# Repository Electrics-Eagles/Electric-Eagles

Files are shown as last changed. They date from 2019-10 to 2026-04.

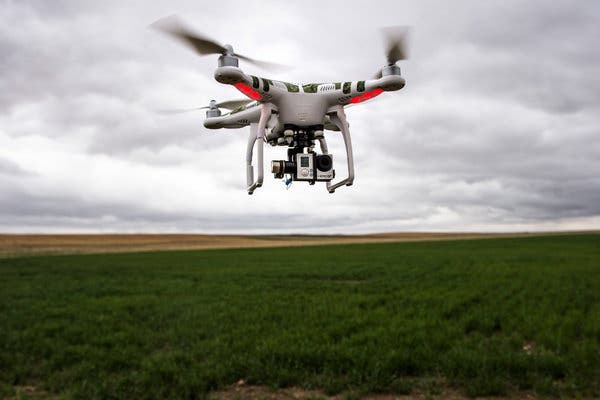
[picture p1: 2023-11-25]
Studio/Electrics Eagles Setup Studio/src/main/resources/Wirzard.FXML/template/dji.jpg

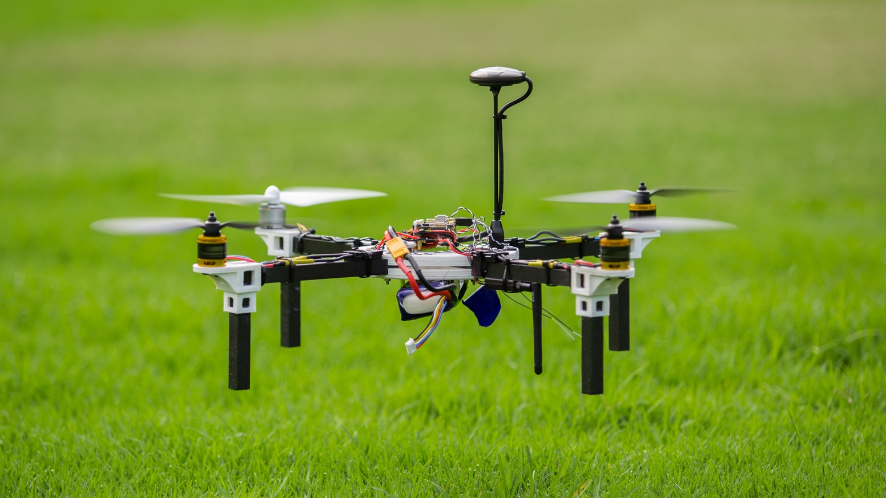
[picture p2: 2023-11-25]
Studio/Electrics Eagles Setup Studio/src/main/resources/drone_imange.jpg

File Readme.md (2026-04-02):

# Electric Eagle Drone Project
Project Overview  
The Electric Eagle Drone Project is a collaborative effort led by a team of three dedicated individuals:  
* Alex Zaslvskis
* Mike Zaslvskis
* Daniel Zile

# Objectives
Our primary objective was to create a simple and flexible platform for developing Arduino-based drones. The project is an ongoing endeavor, and you can find detailed information on our official website.

# Technologies and Tools Used
During the creation of this project, we utilized various technologies and tools to ensure its success:

1. YMFC-AL Version 1.4: Our flight control software.
2. Arduino IDE 1.8.10 and 1.0.6: The integrated development environment for programming the Arduino boards.
3. Sublime Text 3.22: A text editor for code development.
4. Python 3.7.6: Used for scripting and automation.
5. Java 11u06: Required for certain components.
6. Deviot: An Arduino IDE package manager.
7. Arduino Nano v3 (CH340): The microcontroller used in our project.
8. Motors and ESC from DJI Phantom 1 (FC40): High-quality propulsion components.
9. DJI 450 Frame: The drone's frame for stability and durability.
10. 2200mAh 11.1V Battery: Power source for the drone.
11. SMD Capacitors (1206): Components for electrical stability (2μF, 1μF, 0.1nF).
12. SMD Resistors (1206): Components for electronic control.
13. And your three brilliant minds: Our team's expertise and creativity.
# Acknowledgments
We extend our sincere gratitude to our physics teacher,George Dalidovich, for providing invaluable guidance and support throughout this project.
# What next
For further details and updates, contact us on GitHub or email:  electricseagles2020@gmail.com

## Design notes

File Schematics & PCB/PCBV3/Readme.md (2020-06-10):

These PCB board was update signal to PPM mode for transmit. Instead of four pmw mode pin. 
Additionally, we added GPS module for our drone. It will second board.

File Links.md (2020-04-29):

Add Here any links that we use for making drone.
-------------------------------------------------------PID--------------------------------------------------------
 https://oscarliang.com/quadcopter-pid-explained-tuning/
https://www.crossco.com/blog/basics-tuning-pid-loops/
https://profpv.ru/chto-takoe-pid-na-chto-vliyaet-i-kak-nastroit/
https://www.youtube.com/watch?v=tgQDJ73w7Uc
https://habr.com/ru/company/technoworks/blog/216437/
https://github.com/it-workshop/Quadrocopter/wiki/Software
https://habr.com/en/post/145991/
https://habr.com/en/post/143388/
https://multicopterwiki.ru/index.php/Теория_настройки_ПИД_/_PID
https://clever.coex.tech/ru/pid_tuning.htmlw
https://sites.google.com/site/webstm32/pid_reg
https://habr.com/ru/post/227425/
http://jsfiddle.net/limon_spb/ZPmPh/
https://dspace.ucuenca.edu.ec/bitstream/123456789/21401/1/IEE_17_Romero%20et%20al.pdf
http://isd-soft.com/tech_blog/tuning-pid-regulator/

--------------------------------------------------------PID---------------------------------------------------------

--------------------------------------------------------Drone_making------------------------------------------------
http://www.electronoobs.com/eng_robotica_tut6_1.php
http://andrew.gibiansky.com/downloads/pdf/Quadcopter%20Dynamics,%20Simulation,%20and%20Control.pdf
https://www.slideshare.net/mobile/corradosantoro/quadcopter-31045379
https://www.google.co.uk/amp/s/www.wired.com/2017/05/the-physics-of-drones/amp
https://diymodeling.appstate.edu/sites/diymodeling.appstate.edu/files/drone.pdf
https://www.quora.com/What-are-the-mathematics-of-drone-quadcopter-flight-stabilization
http://archives.math.utk.edu/ICTCM/VOL27/A029/paper.pdf
https://howtomechatronics.com/tutorials/arduino/arduino-brushless-motor-control-tutorial-esc-bldc/
https://howtomechatronics.com/tutorials/arduino/arduino-brushless-motor-control-tutorial-esc-bldc/
https://www.youtube.com/watch?v=kyX9cRxJNdo
https://www.youtube.com/watch?v=DYpHB-LfloI&t=4s
http://www.brokking.net/ymfc-al_main.html
--------------------------------------------------------Drone_making------------------------------------------------
--------------------------------------------------------Usage of Drones---------------------------------------------
https://www.dummies.com/consumer-electronics/drones/popular-uses-for-drones/
--------------------------------------------------------Drone phyics------------------------------------------------
https://www.quora.com/Why-cant-all-the-motors-of-a-quadcopter-rotate-in-the-same-direction
--------------------------------------------------------------------------------------------------------------------

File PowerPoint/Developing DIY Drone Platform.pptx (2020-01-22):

## Developing DIY Drone Platform. Working with GitHub.

## FFirst of All we should to finish a team group.

- 1) Dayo
- 2) Flami
- 3) Jaan
- 4) TJ ?

## Second Task is a understand our project name.

- My Idea is Electrics Eagles Open Source Arduino based Drone Development platform . Shortly EEOSABDDP.

## Also We need to made short and remembered name for (DDP)*

- *Drone development Platform.

## After I we should to plan our project.

- Read Rules
- Start Answer Questions. (Maybee Jaan)

## We need to think about our Software / Hardware Products names.

## Ask yourself are you ready to hard work?

## We should decide so what who do.

- Hardware Planning Everybody.
- Making Library from our code Mike
- Write Normal Sublime Text 3 & VS Code Plugins Danio
- PC Software ( Setup Wizard , first check status designer … ) Alex
- Writing report ( Somebody else ( Jaan)).
- Make tutorials (Everybody)

## What we had now.

- 1) Bad working Sublime Text 3 Plugin
- 2) Drone Core Firmware
- 3) Flying hardware.
- 4) Some references.
- We should:
- Make Hardware easyer
- Rewrite Sublime Text Plugin
- Write PC Tool
- Write Report
- Make tutorials.
- Pack Core Firmware as Library

## Programming Lanuages

- Sublime Text 3 & Vs Code Plugin (Python + CSS+ Pyside2)
- PC Tool is a Java
- Drone Core is a C++ / C / asm

## Working with GitHub.

## How Work With GitHub.

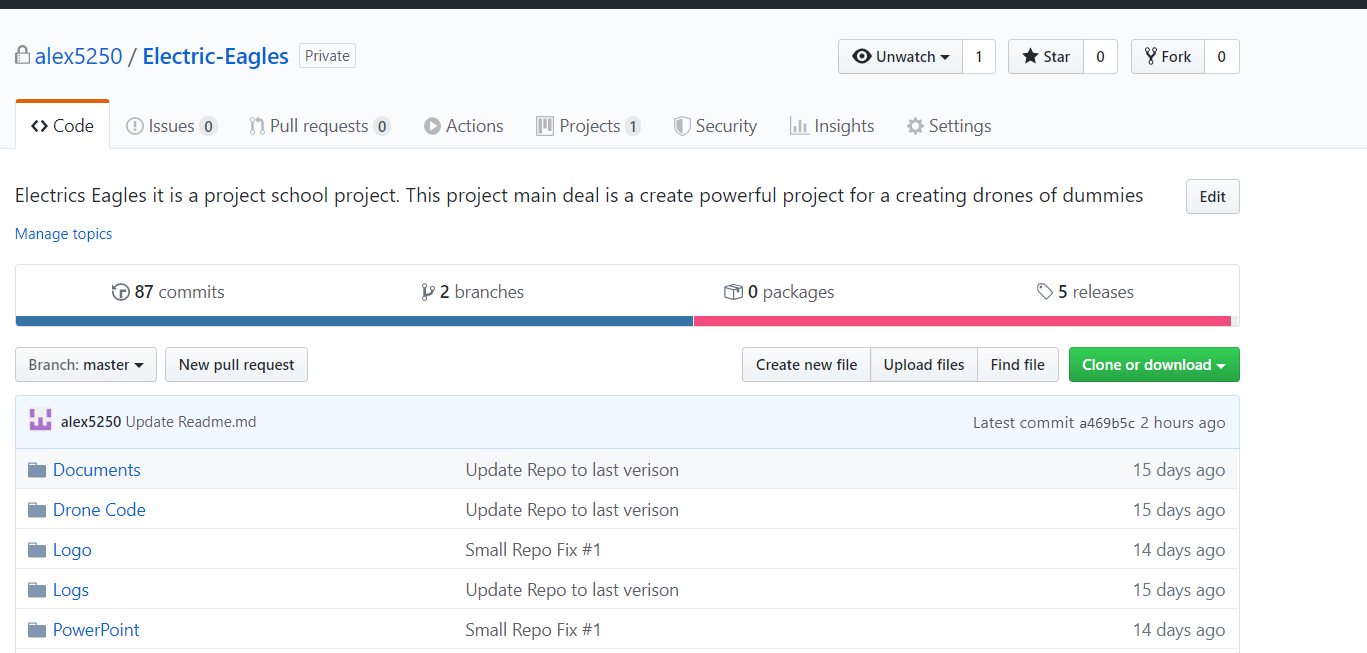
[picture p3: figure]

## Anyway our GitHub is a large difficult system. It has a chart witch helps found what you need.

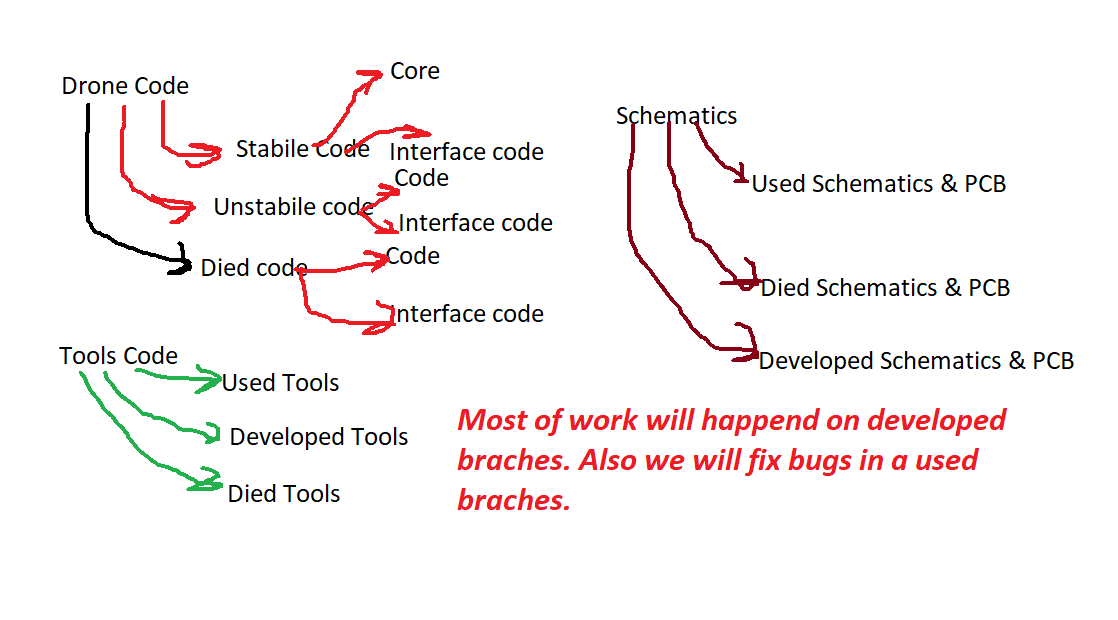
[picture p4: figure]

## Working with GitHub.

- First of all you should register on it. After it send your nickname to me I will add you to our repo.
- Main Idea of it that everybody can edit code, add resources ,fix bugs, add tasks. So I don`t do everything.

## We had a some interesting parts of GitHub Repo. It is a project.

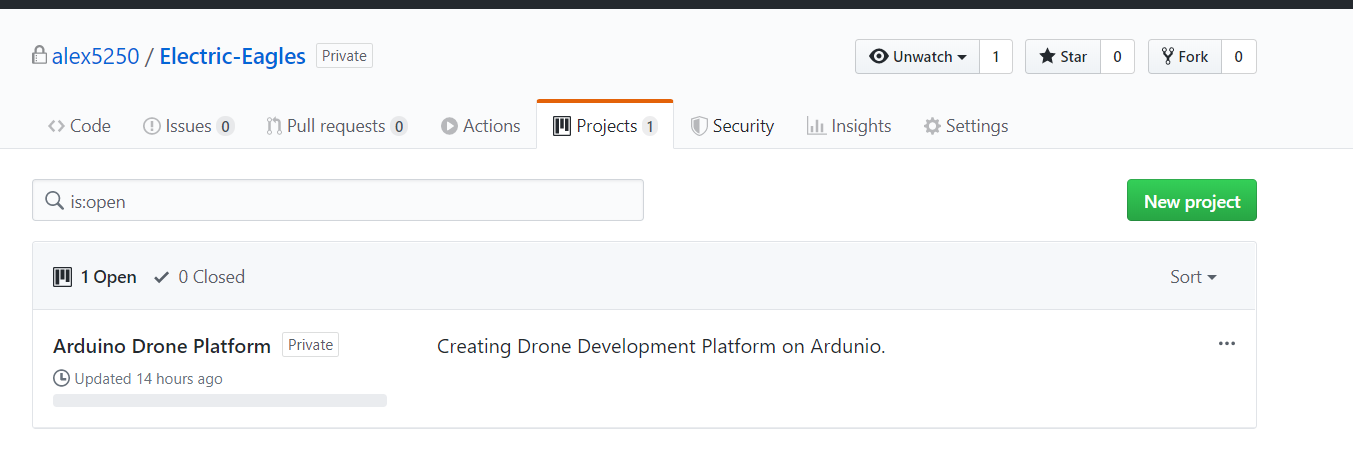
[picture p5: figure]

## Here is written all tasks that we do. You can take it move it to progress and write your name. If you done task move it to done.

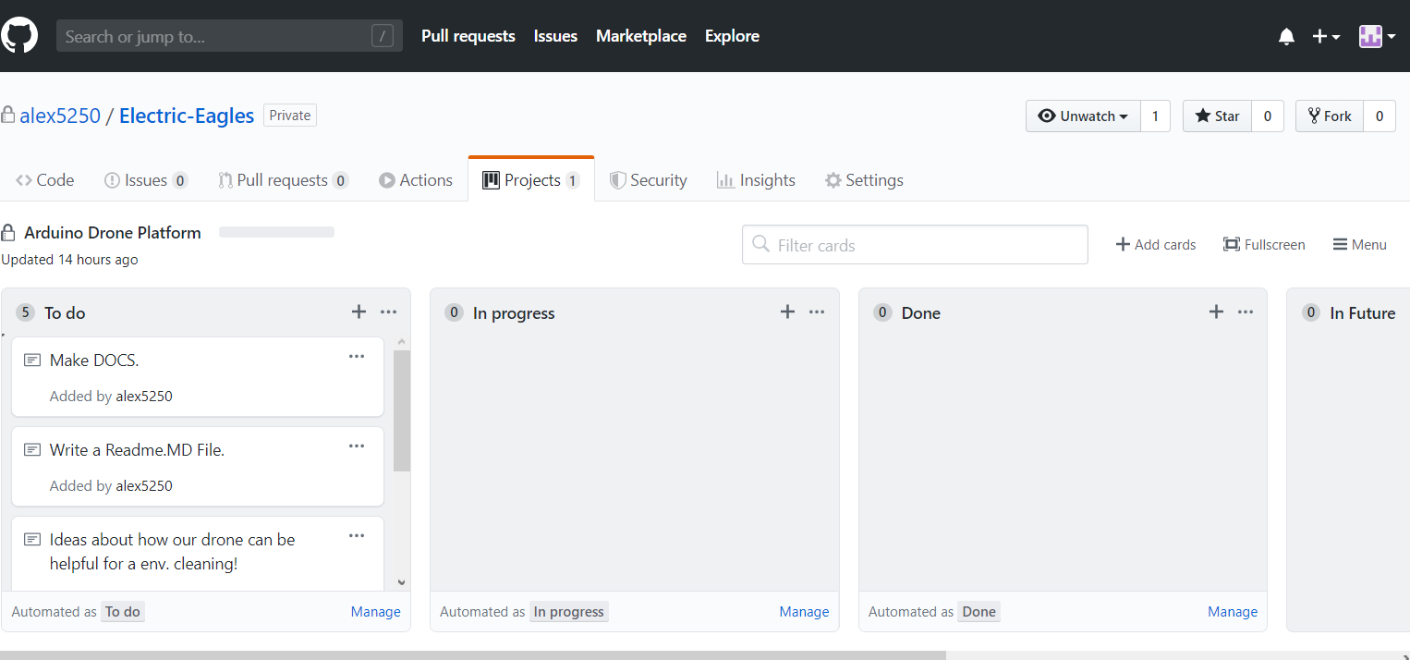
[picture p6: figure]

Alex

Alex

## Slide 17

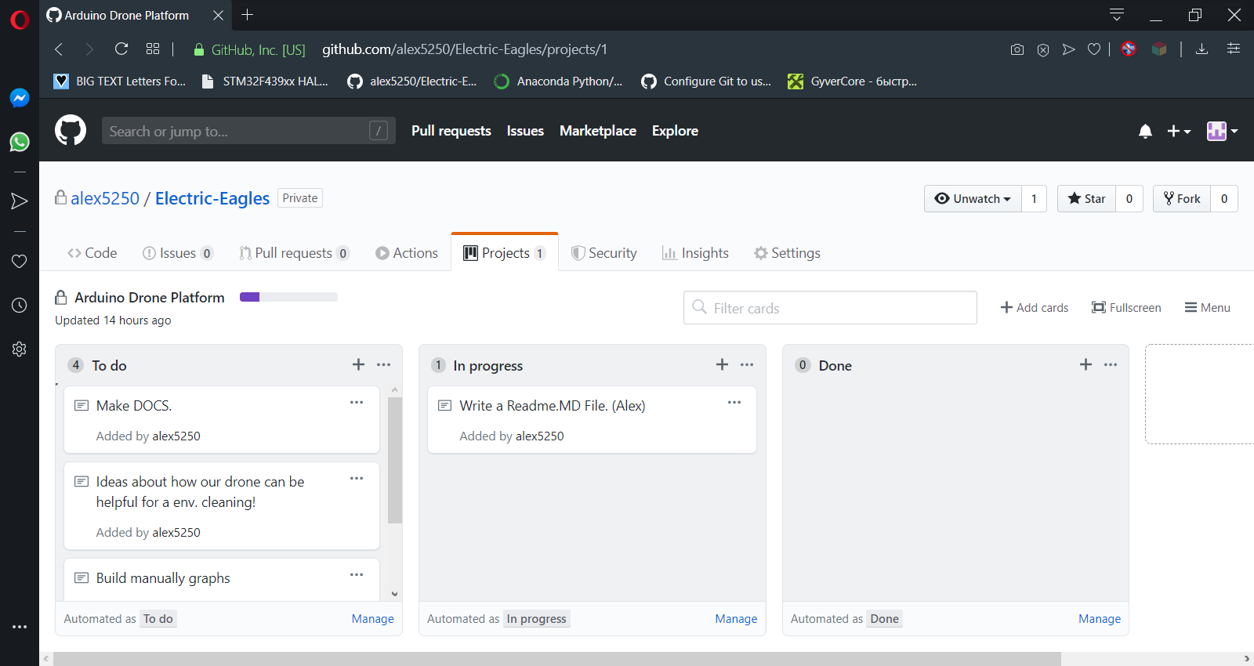
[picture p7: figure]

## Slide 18

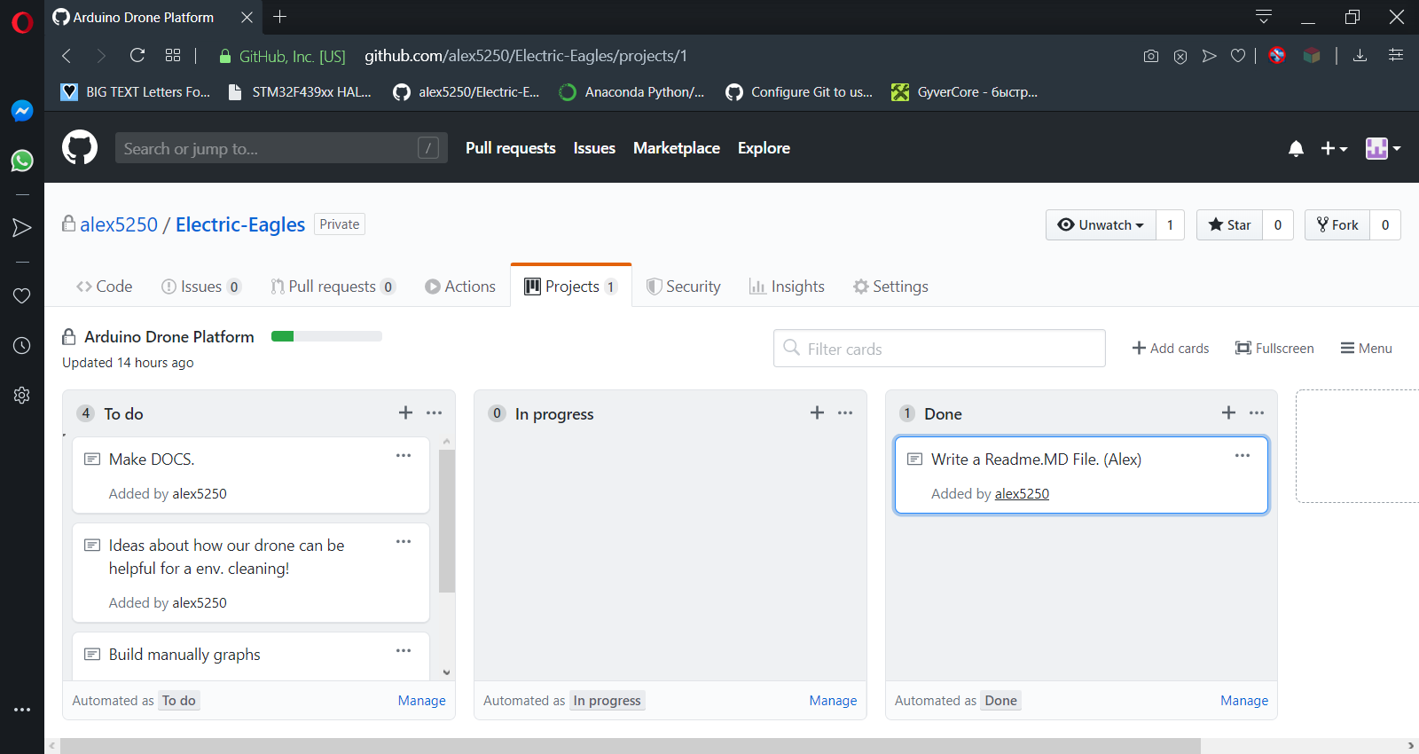
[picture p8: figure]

## If you found a bug in code & hardware. Make report in Issue page. Explain it mostly understandable that you can.

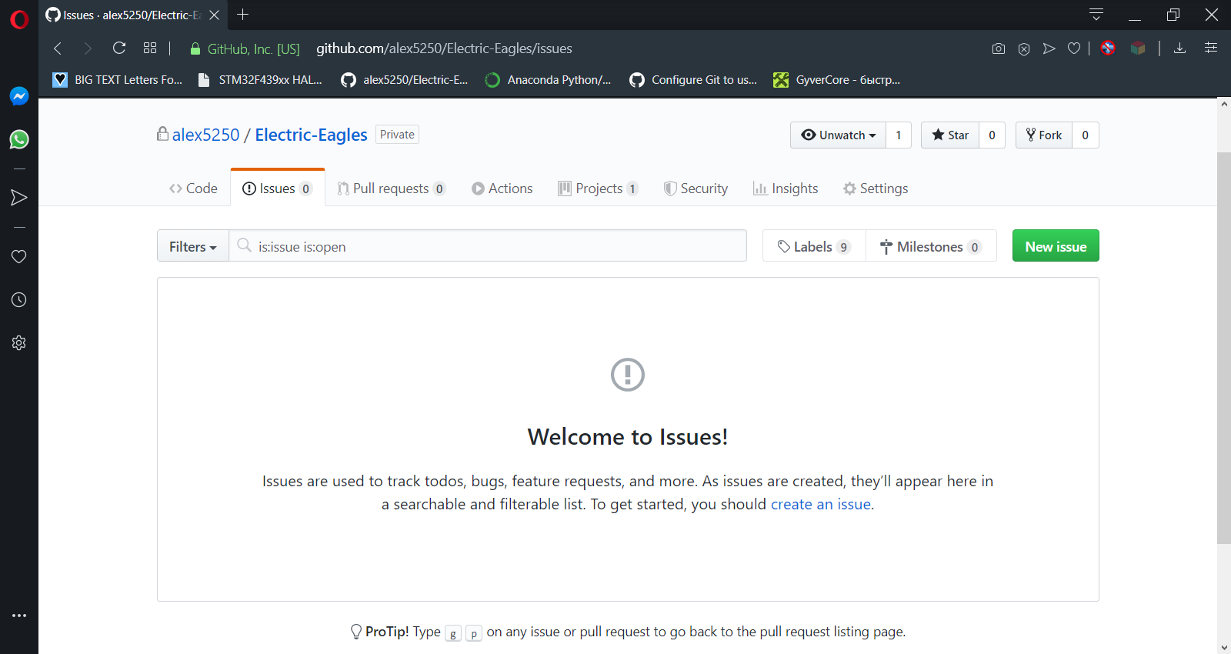
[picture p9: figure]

## All links goes here.

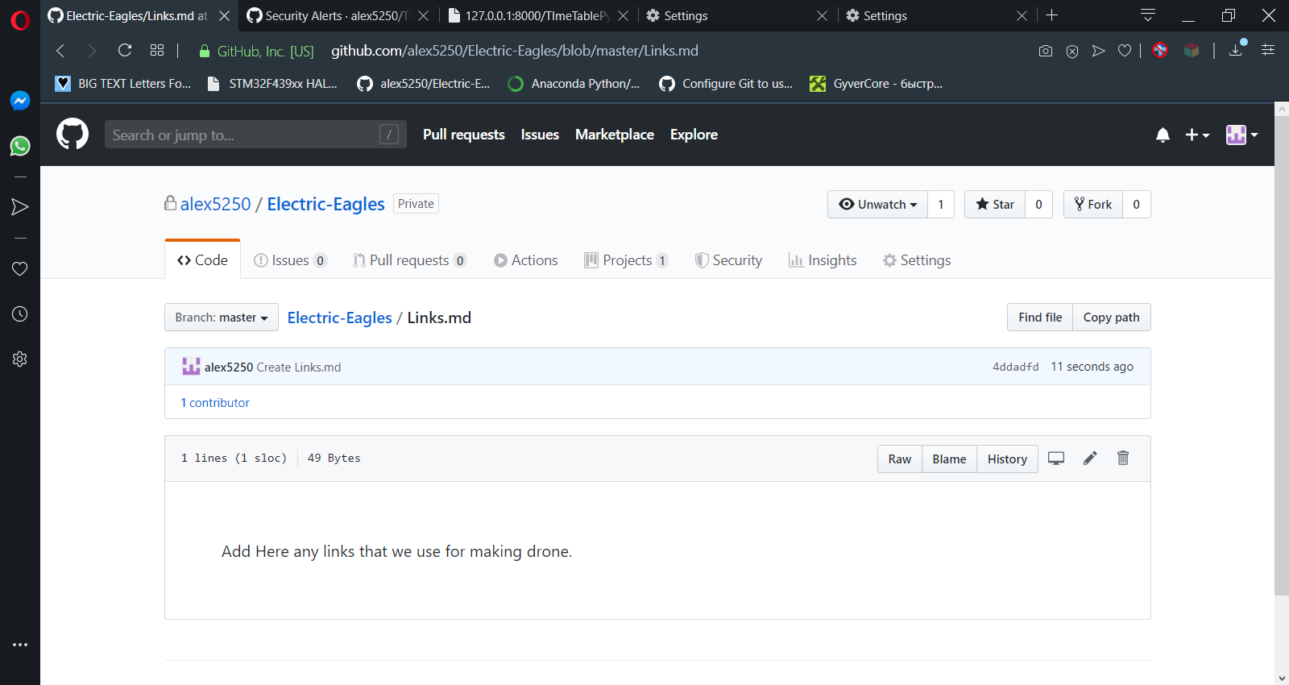
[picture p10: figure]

## Any actual software you can found it releases branch.

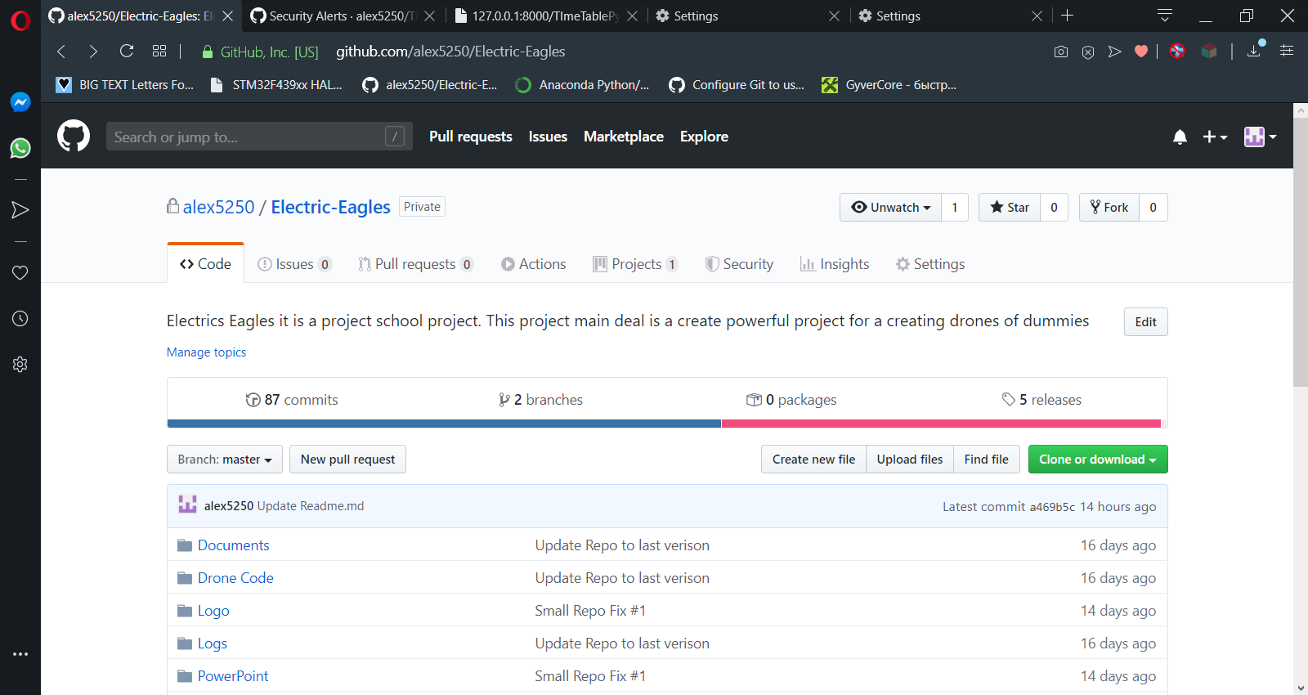
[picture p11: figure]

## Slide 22

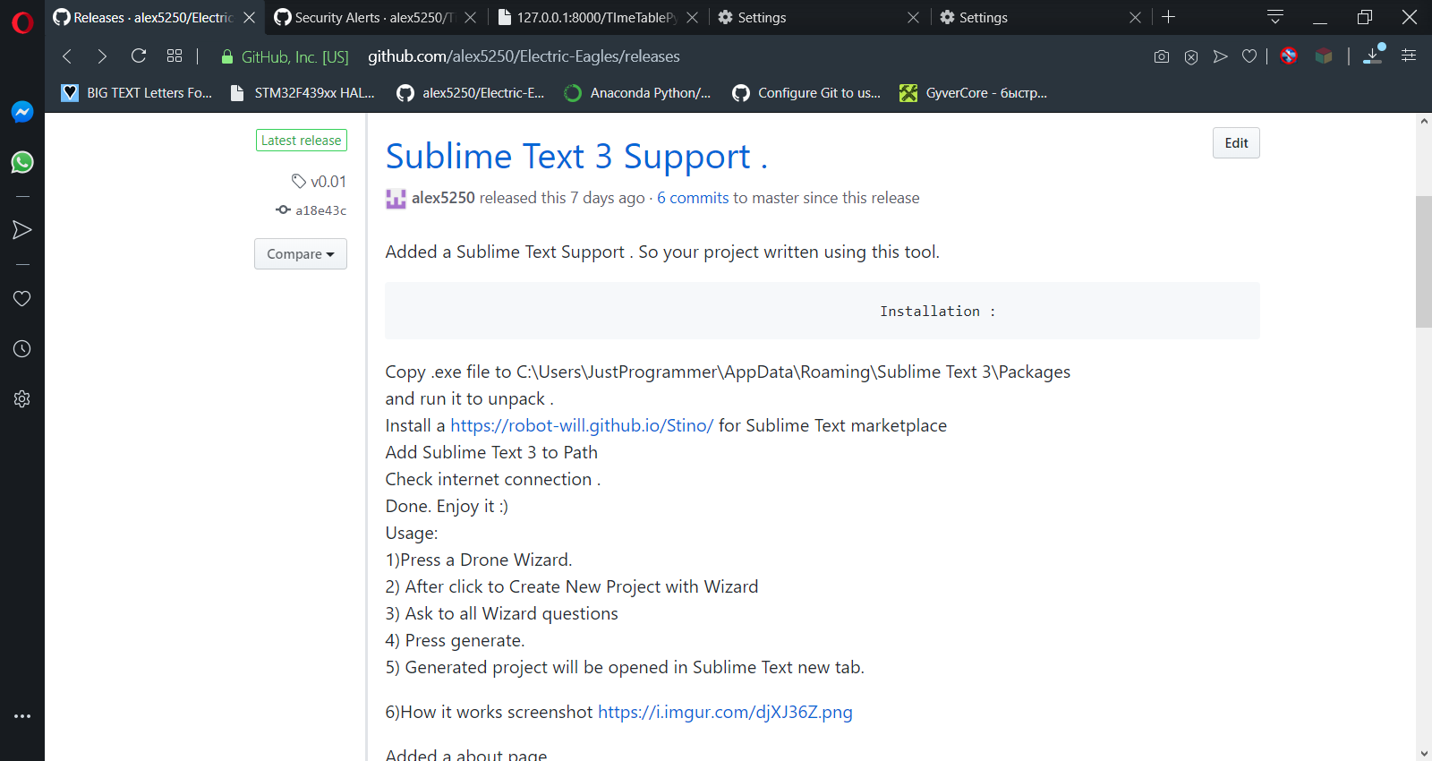
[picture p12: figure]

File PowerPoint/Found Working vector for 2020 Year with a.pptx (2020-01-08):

## Found Working vector for 2020 Year with a drones

## Also Working With Gyro Data Maybe we had a problem with vibration isolation.

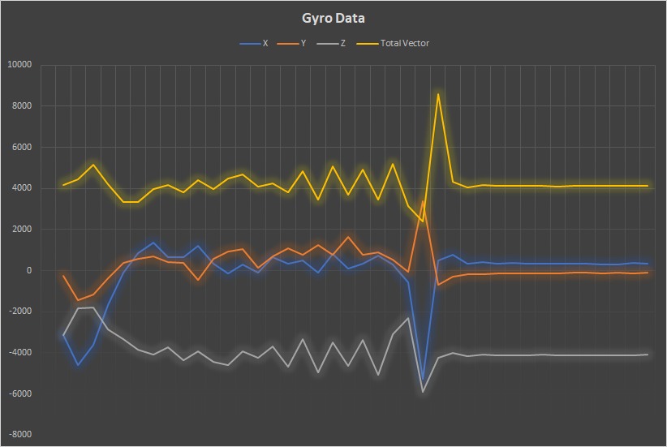
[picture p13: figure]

## Also We can try too work with subtrims

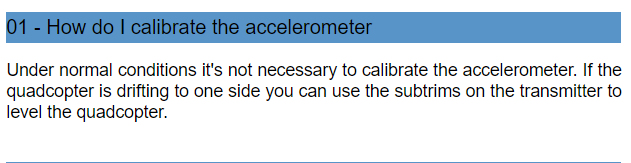
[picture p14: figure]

## Also We can do this one and make SOLUTION

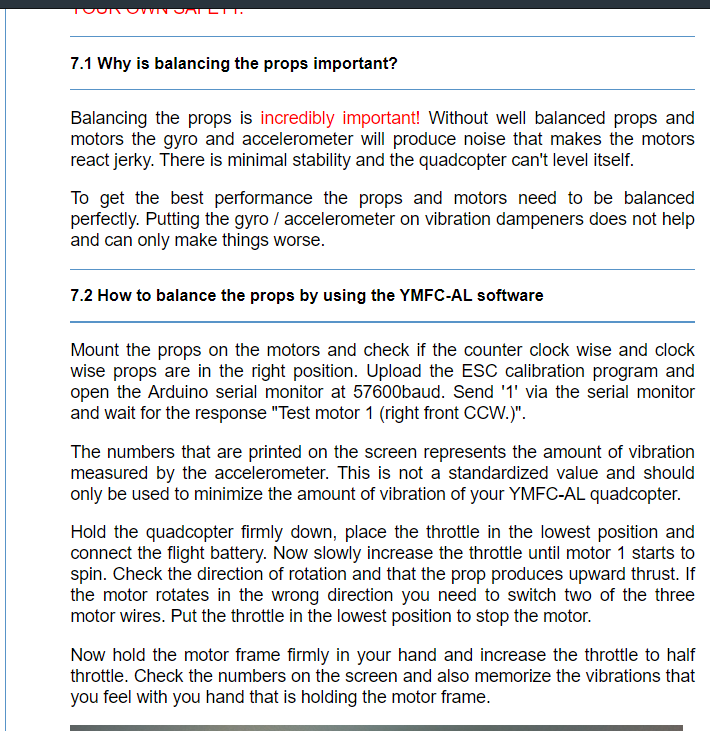
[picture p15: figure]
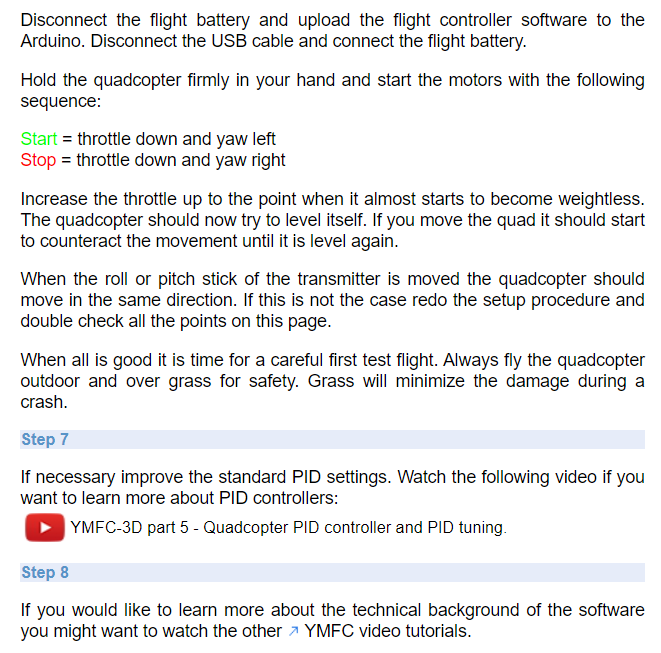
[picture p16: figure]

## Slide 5

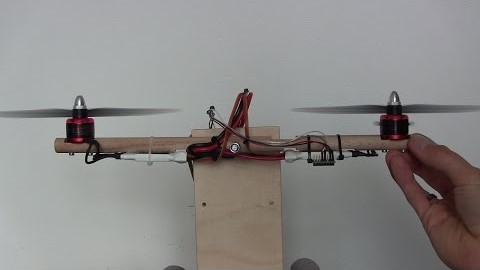
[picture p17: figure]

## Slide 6

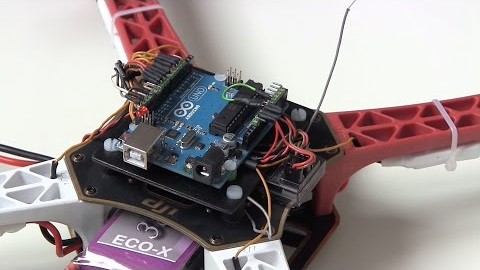
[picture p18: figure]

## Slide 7

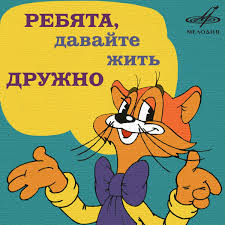
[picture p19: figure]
Картинки по запросу ребята давайте жить дружно
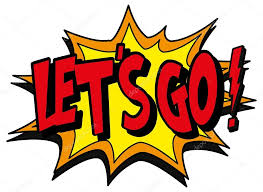
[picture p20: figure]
Картинки по запросу дуеёы пщ

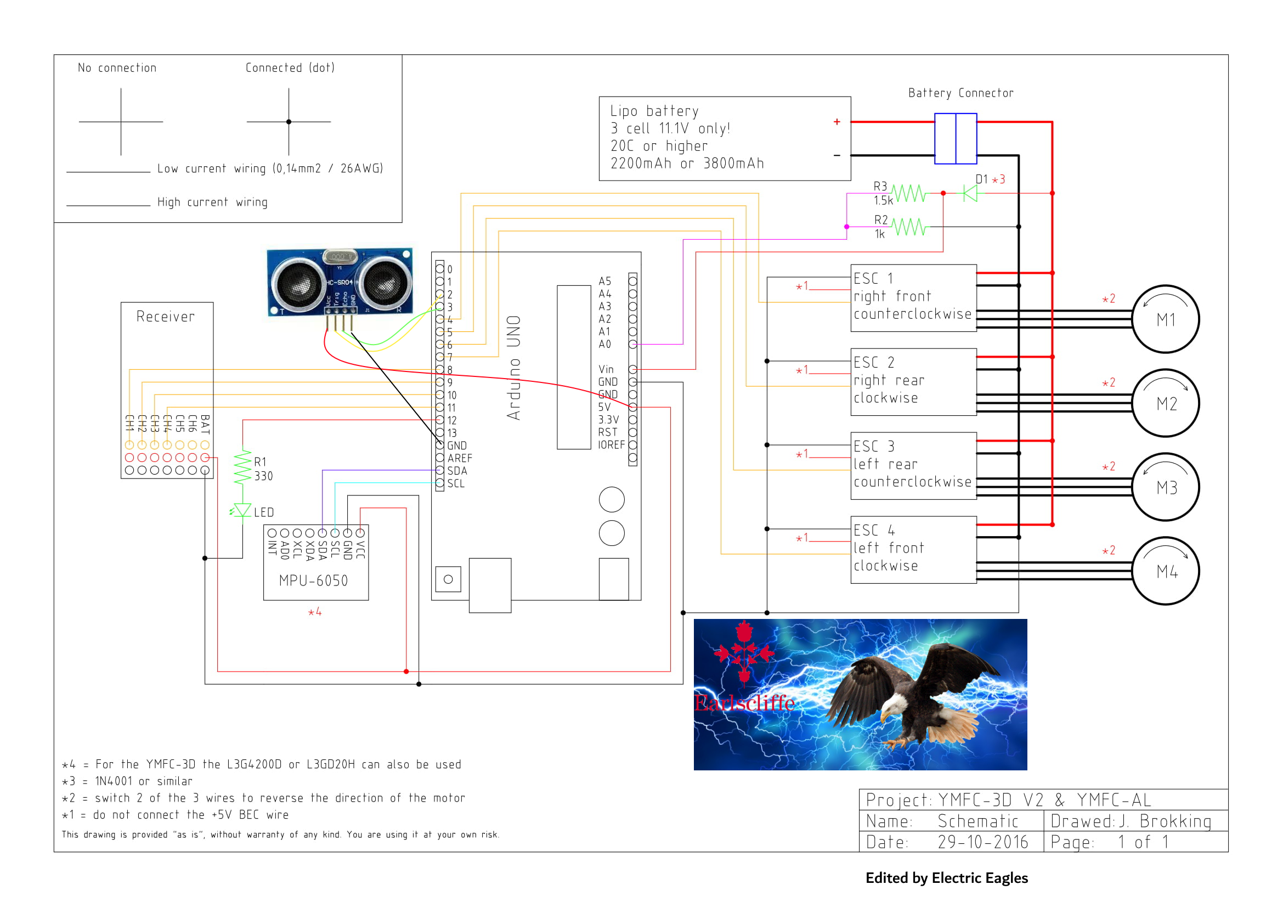
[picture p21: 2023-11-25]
Schematics & PCB/Drone PCB/EarclifeDrone_schematic.png

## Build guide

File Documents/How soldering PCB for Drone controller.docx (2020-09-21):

How soldering PCB for Drone controller

You may need before do:

List necessary components

Name of components | Qty. (pcs) | Number components in PCB | Remark | Link to ordering components
Diode M7 | 1 | D1
Resistor 1.5 kohm with size SMD1206 | 1 | R1 | Size SMD with code 1206
Resistor 1 kohm with size SMD1206 | 1 | R2 | Size SMD with code 1206
Ceramic capacitor with size SMD1206 | 1 | C1 | Size SMD with code 1206
Electric capacitor 470 µF | 1 | C2 | Or any capacitor with recommend more than 220 µF. And minimal voltage requirement more 16 V.
L7805 voltage regulator | 1 | 7805
MPU6050 gyroscope board | 1 | U2
Arduino nano | 1 | ARD1
Buzzer with generator, which it compuse less than 40 mA and normal voltage 5 V | 1 | U3
PCB with provided circuit | 1
2.54mm 3-pin header male with angle 90° | 4 | With short text about ESC | For connect each ESC to flight controller
Wire with female header 2.54 mm | 6 (with mixed color of wires) | U1 | For receiver Fly-sky

1. Solder SMD-components, which resistor and capacitor with following normal value and number of places of this PCB.
2. Solder electric capacitor and buzzer, but it is very important follow polarity where marked symbol “+” – plus polarity. Otherwise polarity, may be damage these components.
3. Solder L7805 voltage regular. Follow correct pin of L7805 into board. Follow picture.
4. Solder wires for receiver Fly-sky. If you have two header female in each wire, cut one this header of wire. Clear bit part isolation of each wire. Solder wire into board with following number of components.
5. Gyroscope and Arduino nano controller provided header male with apporation number of pins.
  5.1 First solder header into these boards.
  5.2 Pick these modules into PCB, but you need make sure correct pin before soldering. Follow this picture below. Be carefully! Otherwise, board may death if incorrect pick module into board. You may need to check correctly pin via multimeter. Simple test polarity between modules and PCB.
  5.3 Recheck your soldered board, before connect power, include pins for receiver and ESC. Sometimes don’t marked polarity in PCB. You can find polarity via multimeter where it is plus and minus, pin, signal. Follow picture below.

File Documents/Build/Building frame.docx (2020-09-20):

Building frame

1) Step one take the lowest holder and turn it back
2) Install red motor holder
  a. Be careful the red motor holder should be on dig anal of red one .

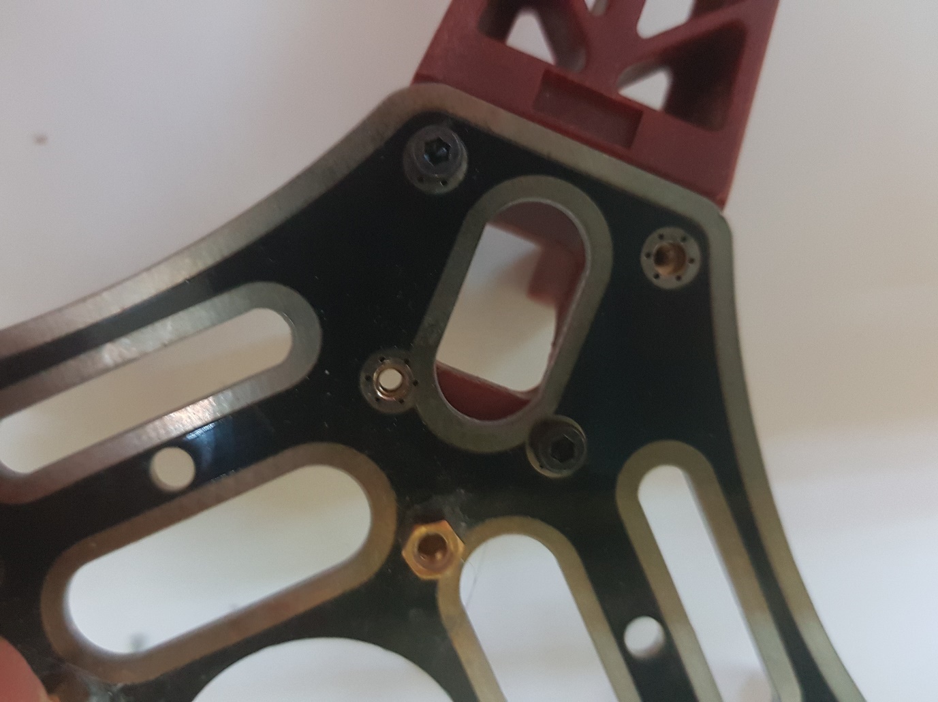
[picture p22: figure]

Warring . Install 4 screws and make sure that they installed correctly

Continue this for 3 left motor holders .

As result you should get :

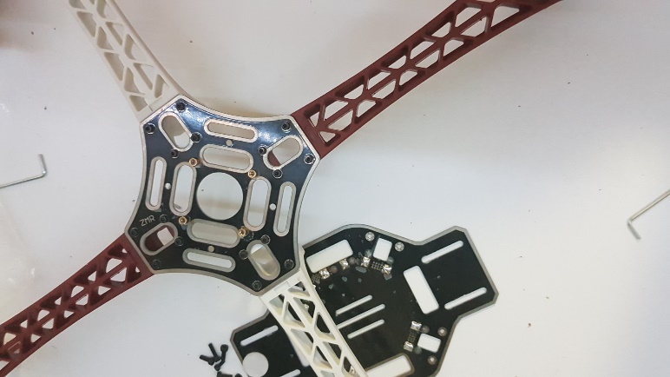
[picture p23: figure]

Turn back the drone:

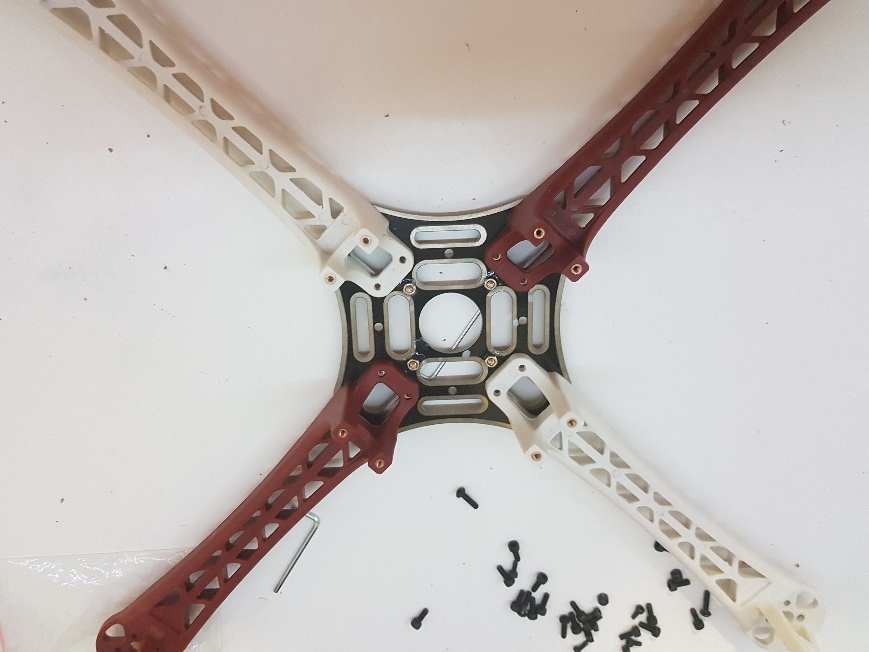
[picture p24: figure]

Turn over down plate and install it by 2 screws:

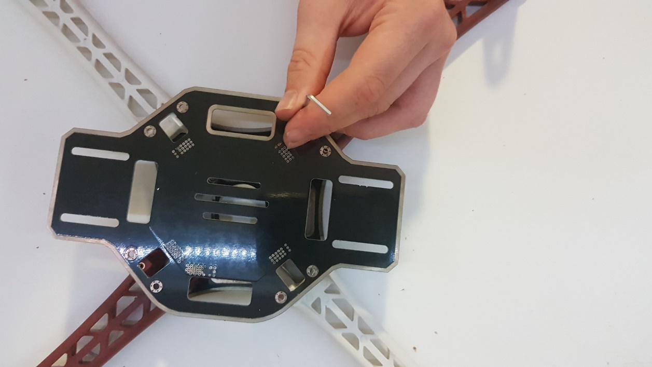
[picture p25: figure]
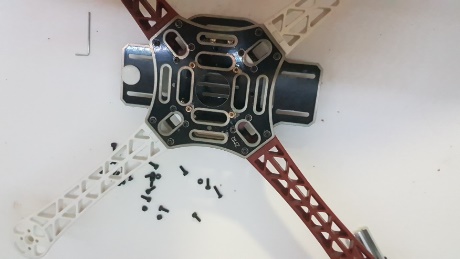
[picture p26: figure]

Turn it back and result you should get:

Is motor install time

Check motors

Warring has different rotation so same colour screw motors should be installed diagonally

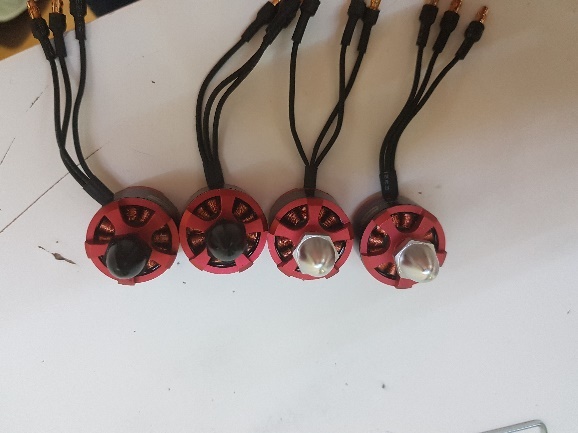
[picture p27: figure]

Like that:

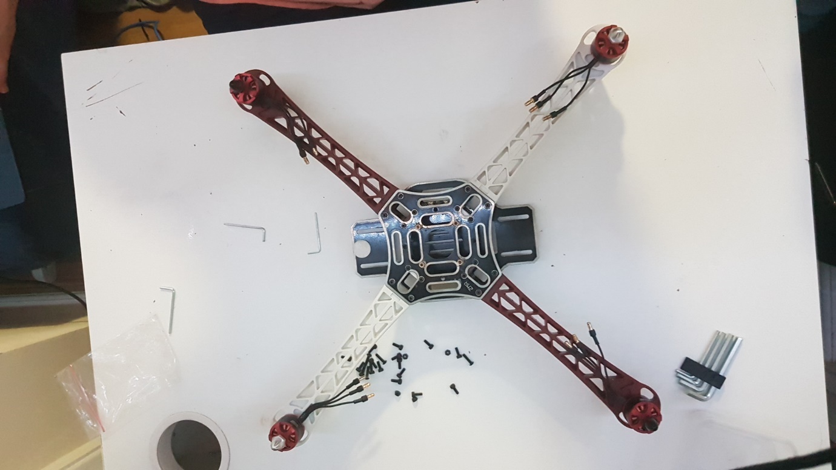
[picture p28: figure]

After it install by 4 screws. Be careful use correct motor length. Do not break motors:

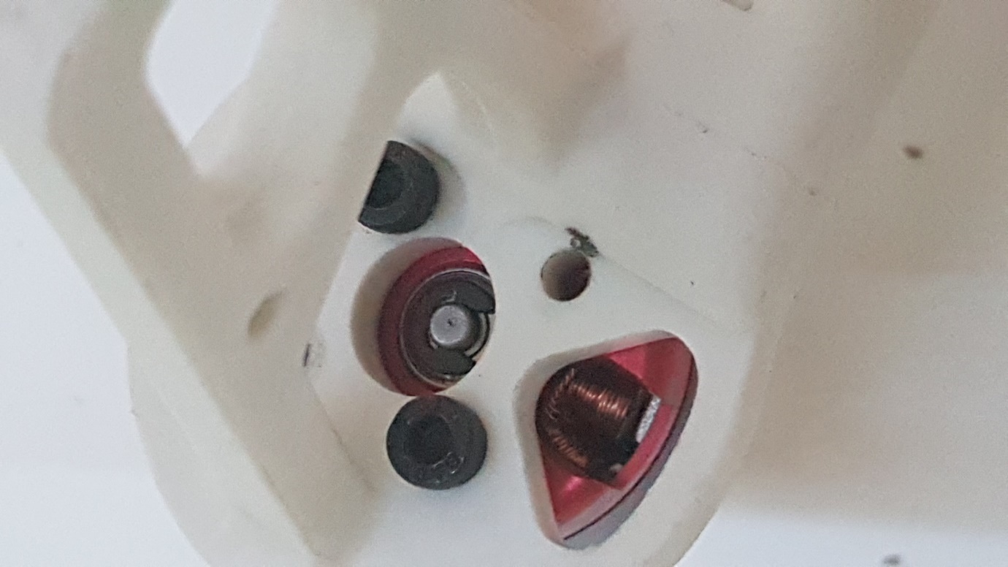
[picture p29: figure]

Is time to install ESC.

The rotation is different so install it now as it happened. After use setup code you fill fix it.

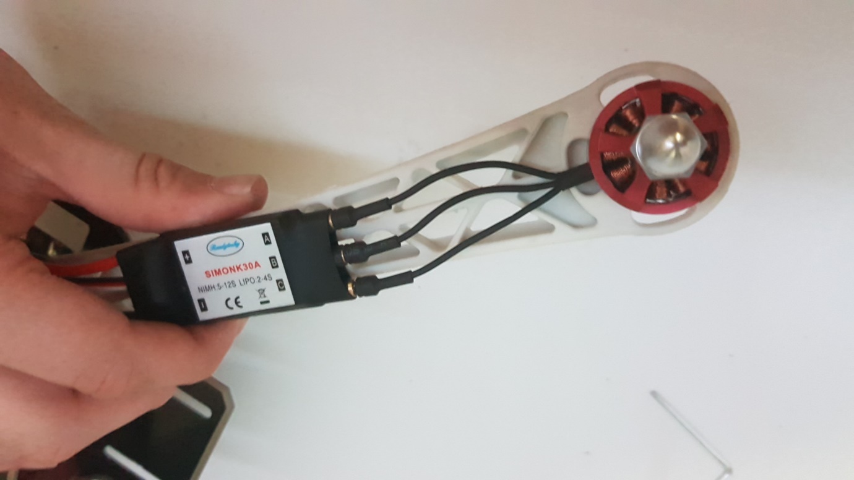
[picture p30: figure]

Do not forget to install it properly

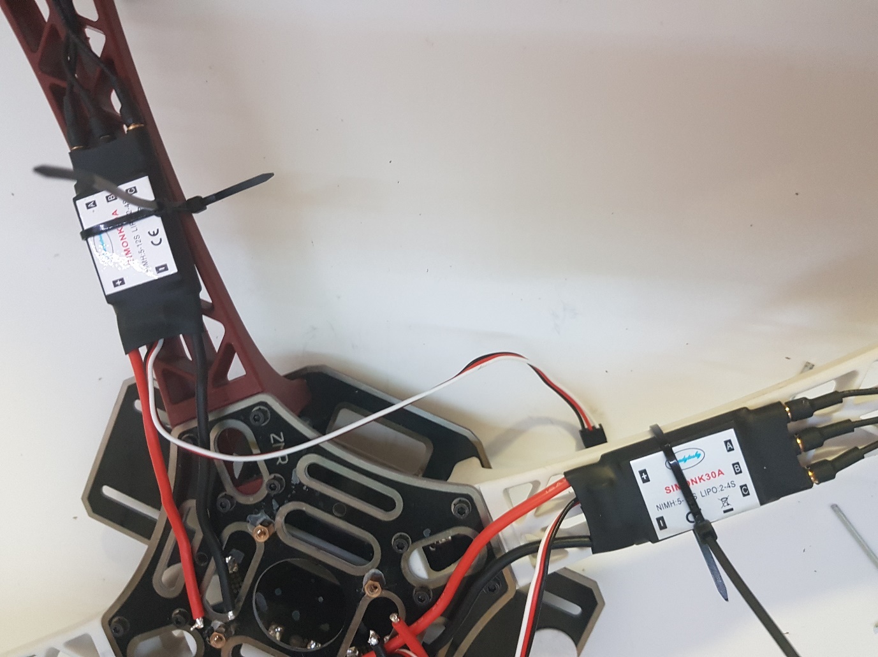
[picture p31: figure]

Well we are installed the minimum frame for flight. In next tutorial we will make brains.

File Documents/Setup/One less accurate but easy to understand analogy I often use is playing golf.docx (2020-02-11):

One less accurate but easy to understand analogy I often use is playing golf. What PID does, is like trying to get the golf ball into the hole. Every time you hit the ball, it might end up too far, or too short, but hopefully it gets closer and closer. You repeat until you eventually get it.

PID tuning is like improving your golf skills, so you can get the golf ball into the hole in as few strikes as possible.

P gain determines how hard the flight controller works to correct error and achieve the desired flight path (i.e. where the pilot wants the quad to go by moving the transmitter sticks).

Think of it as a sensitivity and responsiveness setting. The snappy response provided with a high P gain can even make it feel like you have increased your rates.

Generally speaking, higher P gain means sharper control while low P gain means softer control.

If P is too high, the quadcopter becomes too sensitive and tends to over-correct, eventually it will cause overshoots, and you will have high frequency oscillations.

You can lower P to reduce the oscillations, but reduce it too much and your quadcopter will start to feel sloppy. I term determines how hard the FC works to hold the drone’s attitude against external forces, such as wind and off-centered CG.

Think of it as the stiffness setting in the stall motion of your quadcopter, and how well it holds its attitude.

In Betaflight, default I gain works pretty well on most setups. But if you notice some drifting without user command, then increase it. When I is too low you might find yourself having to correct the quad’s flying path a lot more with your sticks, especially when you are active with the throttle.

When I gain gets too high, your quadcopter will be overly constrained by this, and start to feel stiff and unresponsive. It’s similar to having a slower reaction and a decreased P gain. Excessive I gain in extreme cases can create a low frequency oscillation.

Another issue that I gain can address or improve is “throttle dips“.

In the real world, no two ESC’s, motors or propellers are identical, thus they will provide different levels of thrust even when spinning in the same air. When you do a punch out and immediately lower your throttle, one motor might increase and decrease RPM faster than the others, this will cause an unwanted dip movement.

D gain works as a damper and reduces the over-correcting and overshoots caused by P term. Like a shock absorber stops the suspension from being bouncy, adding D gain can “soften” and counteract the oscillations caused by excessive P gain, as well as minimizing propwash oscillations.

When D is too low, your quad will have bad bounce-backs at the end of a flip or roll, and you will also experience the worst propwash oscillations in vertical descents.

Increasing D gain can improve these problems, however, an excessive D value can introduce vibration in your quadcopter because it amplifies the noise in the system. Eventually this will lead to motor overheat and quad oscillation

Another side effect of excessive D term is the decrease in the quad’s response, this effect is often described as “mushy”.

Advices for PID Calibrate drone:

1. Backup your current PID values, so you can go back if something goes wrong
2. Always tune your quad in Rate Mode (aka Acro Mode)
3. Make sure your quadcopter’s CG (centre of gravity) is right in the middle, CG has an effect on how well your quad will fly, and how easy it is to tune. You can simply shift your battery to move the COG forth and back.

Let`s calibrate drone :

Every time you change a value, you should ask yourself: “is it getting better or worse?” Try to find the peak where the quad has the best flight characteristics before performance starts to degrade again.Tune one axis at a time: first roll, then pitch, and finally yaw. I adjust one value at a time on each axis, starts with P, then D, and finally I. You might need to go back and forth to fine tune each value because changes to one, will affect the others.Tuning a quad can take time, it might take 10 mins, an hour or even days to get a perfect tune. It really depends on the quality of the parts, the build, and especially your expectation!

If Setpoint Weight is high, the quad will feel more snappy, robotic, precise and locked-in, but it will also feel rougher. When it’s low, the quad feels smoother but also looser and more sluggish. Racers prefer to have it higher, while freestyle pilots prefer a lower value. I personally use 0.9-1.0, which I believe is a good balance and should work for most people.

Your hardware configuration plays a big part in the performance of your quadcopter, there are a few things you should check and get right first.

Not all oscillations are caused by high P or D gains. You need to eliminate vibration sources as much as possible on your quadcopter before tuning PID. The balance of motors and propellers, soft-mounting flight controllers and motors, even frame rigidity, can factor in vibrations. With a vibration-free copter, you can set much higher P and D gains for smoother yet more locked-in flight characteristics..

Ideally, the center of gravity (CG) to be right in the middle of your quadcopter, where the 4 motors intersect on a horizontal plane, and be as close as possible to the line of propellers on the vertical plane.

When your CG is off-centered, some motors will have to work harder than others, which will affect stability, cause motors to overheat, and limits your maximum speed.

For example – if the LiPo battery is mounted too far back in a quad, it shifts the CG further towards the rear. Now the 2 rear motors might be pushing at 100%, while the 2 front motors are only at 80%. At this point, if you want to push the throttle harder, you can’t! You quad might wobble back and forth, but it will fail to deliver any extra power because the rear motors have already maxed out. Quadcopters with more centralized mass tend to feel more precise, snappy and responsive. When there is more mass on the outside of a quad, it takes more force to rotate it, and longer to accelerate to the desired velocity. Likewise, due to the higher angular mass and inertia, it’s also harder to stop it from rotating.

That’s why X frames (mini quad frame shape) have taken over the racing drone industry from “H designs” when people realized the benefits. Apart from the frame design, lighter motors and ESC’s also help to reduce rotational inertia.vbs.

Sources : https://oscarliang.com/quadcopter-pid-explained-tuning/

https://www.crossco.com/blog/basics-tuning-pid-loops/

https://profpv.ru/chto-takoe-pid-na-chto-vliyaet-i-kak-nastroit/

https://www.youtube.com/watch?v=tgQDJ73w7Uc

https://habr.com/ru/company/technoworks/blog/216437/

https://github.com/it-workshop/Quadrocopter/wiki/Software

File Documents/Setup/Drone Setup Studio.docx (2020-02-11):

Drone Setup Studio.

Экран 1

При запуске программы узер видет окно загрузки. После этого он видит главное окно. В котором можно запустить первичную настройку. Далее открыть проект в редакторе. Также есть пару кнопок типа настроить пид . включить опции. Настроить калмана. А также кнопка перенастроить дрон. И запустить API . Во второй половине программы есть настройка Борт-компьютера. А именно выбор модели. Выбор установка образа ос. Выбор зап. устройства И возможность казтомизации через qemu.

Первое спросят тип гироскопа. Тип моторов. Динна пропеллеров и примерная масса аппарата. А также аппаратура и тип батареи. А также наличие барометра , компаса и утрасоника и его расположение и положение на корпусе.

Далее спросит манеру полётов на дроне.

При нажати кнопки настроить дрон будет в него заливатся прошивка при этом усер будет это видеть ( прогресс бар) . Далее пойдет калибровка дрона . Пользватель будет видеть анимации того что ему надо сделать. В конце будет запрос настроек PID а ввыше будет показаны рекомендуемые настроки ( получаем с удалённой базы ссылка в конфигах) и настройки Каллмана. Далее усер нажимает далее и ждет прогрузки прогресс бара. Всё дрон настроен.

При нажатии на настроить пид или Каллмана вылетит окно с полями куда можно ввести эти данные. При нажати кнопки запустить API в браузере все откроется. При нажатии кнопки включит опции появится окно конфигуратор. Там будут чекбоксы и т.д. При нажати на кастомизировать через qemu запустится qemu и там можно все настроить чтобы потом сохранит как образ.

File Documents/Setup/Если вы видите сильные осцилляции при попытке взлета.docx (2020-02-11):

- Если вы видите сильные осцилляции при попытке взлета, уменьшайте все кэоффициенты P и D до тех пор, пока аппарат не поднимется в воздух.
- С другой стороны, если аппарат почти не реагирует на управление передаваемое с пульта, увеличивайте коэффициент P.

Коэффициент P (пропорциональный) используется для минимизации ошибки отслеживания и отвечает за скорость отклика, по этому должен быть установлен как можно выше, но без осцилляций.

При настройке коэффициента P пользуйтесь двумя основными наблюдениями:

- Если P слишком большой: вы увидите высокочастотные осцилляции.
- Если P слишком маленький:
  1. Аппарат медленно реагирует на входящее управление
  2. В режиме ACRO аппарат будет постоянно дрейфовать и вам нужно будет его корректировать, чтобы сохранить его уровень.

Коэффициент D (дифференциальный) используется для демпфирования. Этот коэффициент должен быть как можно выше, но таким образом, что бы не было "перестрелов" по управлению.

При настройке коэффициента D пользуйтесь двумя основными наблюдениями:

- Если D слишком большой: моторы могут подергиваться и сильно нагреваться во время полета, поскольку коэффициент D увеличивает шумы управления.
- Если D слишком маленький: возникнут "перестрелы" по входящему управляющему сигналу.

Коэффициент I сохраняет "воспоминания" об ошибке. Это значит, что элемент I увеличивается в случае, если желаемая скорость не устанавливается в течении некоторого времени. Этот параметр важен для режима ACRO, а также оказывает достаточно сильное влияние на режимы POSITION и OFFBOARD.

- Если I слишком большой: вы можете увидеть медленные осцилляции
- Если I слишком маленький: можно заметить ошибку по выполнению управляющего воздействия. Также заниженный коэффициент I заметен на логах, это характеризуется тем, что на графиках желаемая скорость длительное время отличается от фактическо

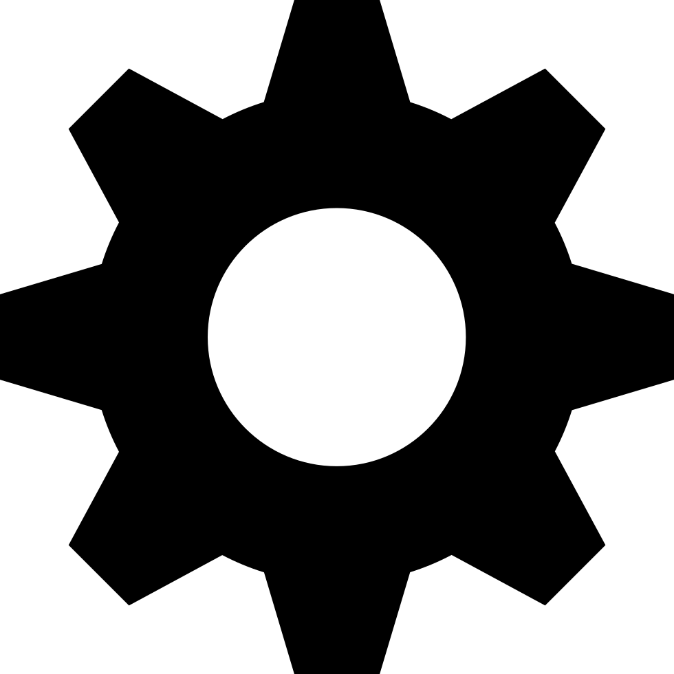
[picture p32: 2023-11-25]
Studio/Electrics Eagles Setup Studio/src/main/resources/setup.png

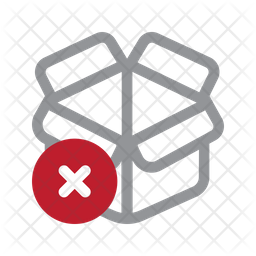
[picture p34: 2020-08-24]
Studio/Electrics Eagles Setup Studio/src/main/resources/remove.png

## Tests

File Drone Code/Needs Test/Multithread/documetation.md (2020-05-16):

Describe and documetation of this code: https://github.com/ivanseidel/ArduinoThread (about thread function/class describe). Thanks Ivan Seidel!
In callback of function for manipulation thread, don't use function delay(), because the task will block. Using void Thread::setInterval(int time) to prevent to block next task; 
If you want few thread and run all equal time, to you need using ThreadController class and add using method of this class .add(). 
Minimal using code for running thread.

```C++

#include <Thread.h>
int ledPin = 13;

//My simple Thread
Thread myThread = Thread();

// callback for myThread
void niceCallback() {
   // add code of task in this thread
}

void setup() {

	myThread.onRun(niceCallback);
	myThread.setInterval(500); // to set interval to next time code run with initail task of callback function
}

void loop() {
	// checks if thread should run
	if(myThread.shouldRun())
		myThread.run();
}
```
Minimal using code for ThreadController 

```C++
#include <Thread.h>
#include <ThreadController.h>

// ThreadController that will controll all threads
ThreadController controll = ThreadController();

// adding class thread
Thread myThread = Thread();
Thread hisThread = Thread();

// callback for myThread
void myThreadCallback() {
    // add code of task in this thread
}

// callback for hisThread
void hisThreadCallback(){
    // add code of task in this thread
}

void setup() {

	// Configure myThread
	myThread.onRun(myThreadCallback); // set callback in this class of thread
	myThread.setInterval(500); // set interval maxiumum to run. If time was expired time to will do task with newly

	// Configure hisThread
	hisThread.onRun(hisThreadCallback); // set callback in this class of thread
	hisThread.setInterval(250); // set interval maxiumum to run. If time was expired time to will do task with newly

	// Adds both threads to the controller
	controll.add(&myThread);  // & to pass the pointer to it
	controll.add(&hisThread); // & to pass the pointer to it
}

void loop(){
	// run ThreadController
	// this will check every thread inside ThreadController,
	// if it should run. If yes, he will run it;
	controll.run();
}

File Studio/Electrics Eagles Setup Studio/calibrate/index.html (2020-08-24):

# Move the throttle stick to full throttle and back to center

# Move the roll stick to simulate left wing up and back to center

# Move the pitch stick to simulate nose up and back to center

# "Move the yaw stick to simulate nose right and back to center

# Gently move all the sticks simultaneously to their extends When ready put the sticks back in their center positions

# Lift the left side of the quadcopter to a 45 degree angle within 10 seconds

# Lift the nose of the quadcopter to a 45 degree angle within 10 seconds" Put the quadcopter back in its original position

# Rotate the nose of the quadcopter 45 degree to the right within 10 seconds

# Put stick from max thollite and back to center

# =

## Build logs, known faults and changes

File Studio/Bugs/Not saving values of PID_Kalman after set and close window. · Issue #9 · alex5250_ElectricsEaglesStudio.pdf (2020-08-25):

alex5250 (https://github.com/alex5250) / ElectricsEaglesStudio (https://github.com/alex5250/ElectricsEaglesStudio) Private

Code (https://github.com/alex5250/ElectricsEaglesStudio) | Issues | 7 (https://github.com/alex5250/ElectricsEaglesStudio/issues) | Pull requests | 1 (https://github.com/alex5250/ElectricsEaglesStudio/pulls) | Actions (https://github.com/alex5250/ElectricsEaglesStudio/actions) | Projects (https://github.com/alex5250/ElectricsEaglesStudio/projects) | Security (https://github.com/alex5250/ElectricsEaglesStudio/security) | Insights (https://github.com/alex5250/ElectricsEaglesStudio/network/dependencies) | Settings (https://github.com/alex5250/ElectricsEaglesStudio/settings)

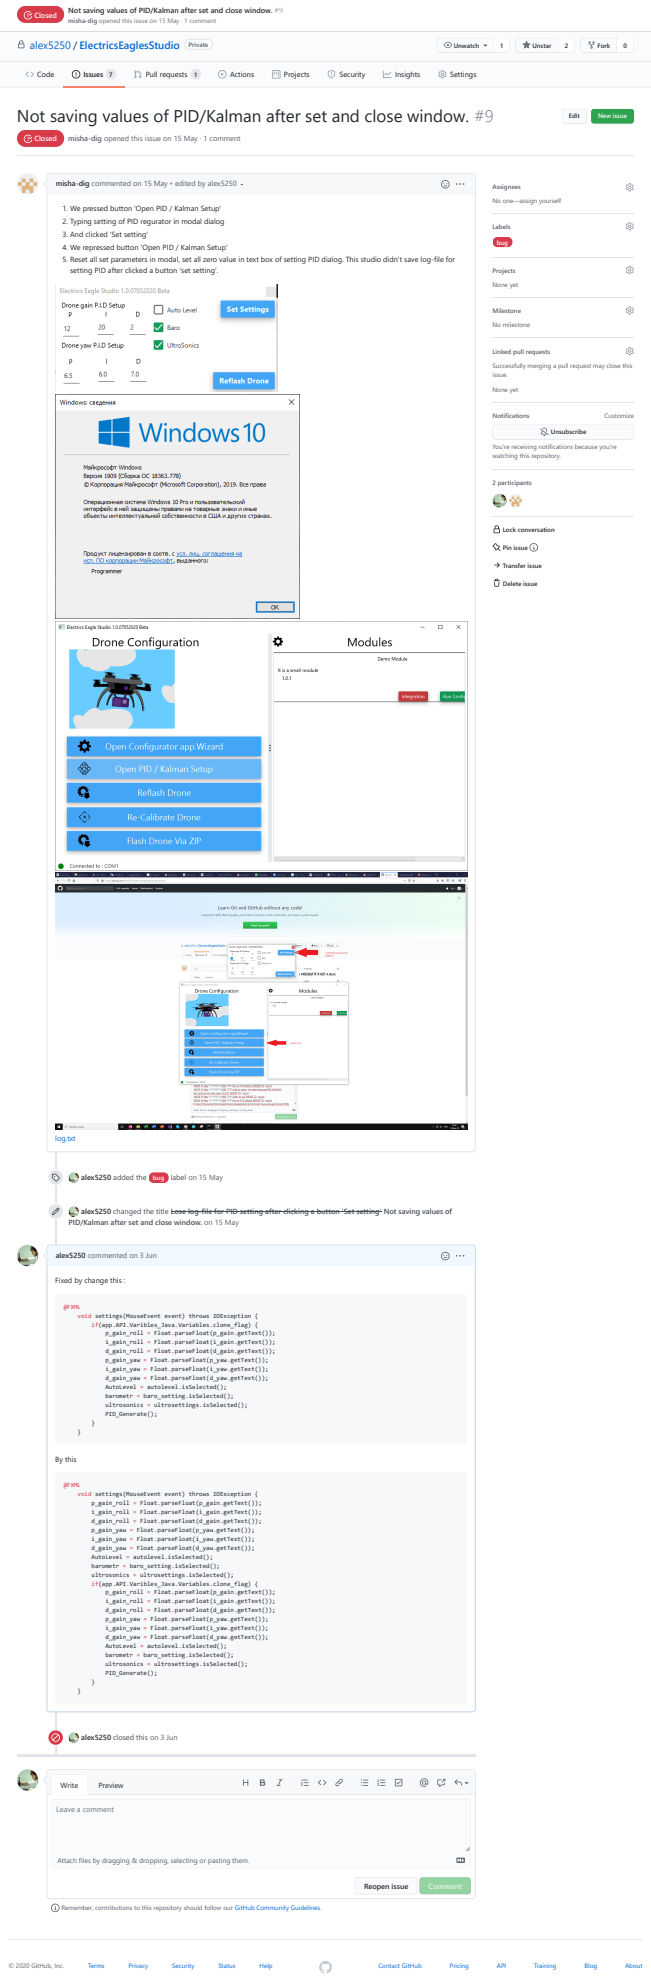
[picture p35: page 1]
Closed; misha-dig opened this issue on 15 May · 1 comment; None yet; No milestone; 2 participants; Lock conversation; Pin issue; Transfer issue; Delete issue; Search or jump to…; Pull requests Issues Marketplace Explore; Unwatch; Unstar; Fork; Edit; New issue; log.txt; edited by alex5250; alex5250 added the; bug; label on 15 May; By this; Leave a comment; Reopen issue; Comment; Labels; Projects; Milestone; Notifications; Customize; Unsubscribe; © 2020 GitHub, Inc.; Terms; Privacy; Security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

misha-dig (https://github.com/misha-dig) opened this issue on 15 May · 1 comment (https://github.com/pulls)

Not saving values of PID/Kalman after set and close window. #9

misha-dig (https://github.com/misha-dig) commented on 15 May •

Assignees
No one—assign yourself

1. We pressed button 'Open PID / Kalman Setup'
2. Typing setting of PID regurator in modal dialog
3. And clicked 'Set setting'
4. We repressed button 'Open PID / Kalman Setup'
5. Reset all set parameters in modal, set all zero value in text box of setting PID dialog. This studio didn't save log-file for
setting PID after clicked a button 'set setting'.

Linked pull requests
Successfully merging a pull request may close this
issue.
None yet

You’re receiving notifications because you’re
watching this repository.

alex5250 (https://github.com/alex5250) changed the title Lose log-file for PID setting after clicking a button 'Set setting' Not saving values of
PID/Kalman after set and close window. on 15 May

alex5250 (https://github.com/alex5250) commented on 3 Jun

Fixed by change this :

@FXML
void settings(MouseEvent event) throws IOException {
if(app.API.Varibles_Java.Variables.clone_flag) {
p_gain_roll = Float.parseFloat(p_gain.getText());
i_gain_roll = Float.parseFloat(i_gain.getText());
d_gain_roll = Float.parseFloat(d_gain.getText());
p_gain_yaw = Float.parseFloat(p_yaw.getText());
i_gain_yaw = Float.parseFloat(i_yaw.getText());
d_gain_yaw = Float.parseFloat(d_yaw.getText());
AutoLevel = autolevel.isSelected();
barometr = baro_setting.isSelected();
ultrosonics = ultrosettings.isSelected();
PID_Generate();

alex5250 (https://github.com/alex5250) closed this on 3 Jun

Attach files by dragging & dropping, selecting or pasting them.
Choose Files No file chosen

Remember, contributions to this repository should follow our GitHub Community Guidelines. (https://docs.github.com/articles/github-community-guidelines)

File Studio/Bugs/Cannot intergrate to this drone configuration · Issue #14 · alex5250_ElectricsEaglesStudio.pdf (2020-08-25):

alex5250 (https://github.com/alex5250) / ElectricsEaglesStudio (https://github.com/alex5250/ElectricsEaglesStudio) Private

Code (https://github.com/alex5250/ElectricsEaglesStudio) | Issues | 7 (https://github.com/alex5250/ElectricsEaglesStudio/issues) | Pull requests | 1 (https://github.com/alex5250/ElectricsEaglesStudio/pulls) | Actions (https://github.com/alex5250/ElectricsEaglesStudio/actions) | Projects (https://github.com/alex5250/ElectricsEaglesStudio/projects) | Security (https://github.com/alex5250/ElectricsEaglesStudio/security) | Insights (https://github.com/alex5250/ElectricsEaglesStudio/network/dependencies) | Settings (https://github.com/alex5250/ElectricsEaglesStudio/settings)

# Cannot intergrate to this drone configuration #14

## Closed misha-dig (https://github.com/misha-dig) opened this issue on 15 May · 2 comments

No one—assign yourself

None yet

No milestone

Successfully merging a pull request may close this issue.
None yet

### 2 participants

Lock conversation

Pin issue

Transfer issue

Delete issue

Search or jump to… | Pull requests (https://github.com/pulls) Issues (https://github.com/issues) Marketplace (https://github.com/marketplace) Explore (https://github.com/explore)
Unwatch | 1 (https://github.com/alex5250/ElectricsEaglesStudio/watchers) | Unstar | 2 (https://github.com/alex5250/ElectricsEaglesStudio/stargazers) | Fork | 0 (https://github.com/alex5250/ElectricsEaglesStudio/network/members)
Edit | New issue (https://github.com/alex5250/ElectricsEaglesStudio/issues/new/choose)

## misha-dig (https://github.com/misha-dig) commented on 15 May •

I clicked a red button 'Integration' in box of Demo Module. After clicked a red button, a message box given question. I clicked a button Yes in message box. And cannot intergrate to drone configuration. I didn`t call the Wirzard before.

## log.txt (https://github.com/alex5250/ElectricsEaglesStudio/files/4636440/log.txt)

[INFO] Fri May 15 21:23:12 MSK 2020 Found boards[Ljava.lang.String;@17f30be6 EXPORT TO : log.txt
[INFO] Fri May 15 21:23:14 MSK 2020 Python is found EXPORT TO : log.txt
[ERROR] Fri May 15 21:23:14 MSK 2020 Python is found EXPORT TO : log.txt
[INFO] Fri May 15 21:23:14 MSK 2020 Load an scene ./src/main/resources/main_window.fxml style type: DECORATED EXPOR 0.0
525.0
494.0
It is a small module
[INFO] Fri May 15 21:23:18 MSK 2020 Open an gui EXPORT TO : log.txt MLANG CONFIG INTEPETER VERISON: 1.0.243532
Intergating...
It is a small module
java.io.FileNotFoundException: null\_01_DroneRelese\_01_DroneRelese.ino (Системе не удается найти указанный путь) at java.base/java.io.FileInputStream.open0(Native Method) at java.base/java.io.FileInputStream.open(Unknown Source) at java.base/java.io.FileInputStream.<init>(Unknown Source)
at java.base/java.io.FileInputStream.<init>(Unknown Source)
at java.base/java.io.FileReader.<init>(Unknown Source)
at Electrics.Eagles.Setup.Studio.main/app.API.Modules.Intepeter.ReadValues.read_config_as_array(Unknown Sour at Electrics.Eagles.Setup.Studio.main/app.API.ScrollVBox.ScrollingVBox$2.handle(Unknown Source)
at Electrics.Eagles.Setup.Studio.main/app.API.ScrollVBox.ScrollingVBox$2.handle(Unknown Source)
at javafx.base/com.sun.javafx.event.CompositeEventHandler.dispatchBubblingEvent(Unknown Source)
at javafx.base/com.sun.javafx.event.EventHandlerManager.dispatchBubblingEvent(Unknown Source)
at javafx.base/com.sun.javafx.event.EventHandlerManager.dispatchBubblingEvent(Unknown Source)
at javafx.base/com.sun.javafx.event.CompositeEventDispatcher.dispatchBubblingEvent(Unknown Source) at javafx.base/com.sun.javafx.event.BasicEventDispatcher.dispatchEvent(Unknown Source)
at javafx.base/com.sun.javafx.event.EventDispatchChainImpl.dispatchEvent(Unknown Source)
at javafx.base/com.sun.javafx.event.BasicEventDispatcher.dispatchEvent(Unknown Source)
at javafx.base/com.sun.javafx.event.EventDispatchChainImpl.dispatchEvent(Unknown Source) at javafx.base/com.sun.javafx.event.BasicEventDispatcher.dispatchEvent(Unknown Source) at javafx.base/com.sun.javafx.event.EventDispatchChainImpl.dispatchEvent(Unknown Source) at javafx.base/com.sun.javafx.event.BasicEventDispatcher.dispatchEvent(Unknown Source) at javafx.base/com.sun.javafx.event.EventDispatchChainImpl.dispatchEvent(Unknown Source) at javafx.base/com.sun.javafx.event.BasicEventDispatcher.dispatchEvent(Unknown Source) at javafx.base/com.sun.javafx.event.EventDispatchChainImpl.dispatchEvent(Unknown Source) at javafx.base/com.sun.javafx.event.BasicEventDispatcher.dispatchEvent(Unknown Source) at javafx.base/com.sun.javafx.event.EventDispatchChainImpl.dispatchEvent(Unknown Source) at javafx.base/com.sun.javafx.event.EventUtil.fireEventImpl(Unknown Source)
at javafx.base/com.sun.javafx.event.EventUtil.fireEvent(Unknown Source)
at javafx.base/javafx.event.Event.fireEvent(Unknown Source)
at javafx.graphics/javafx.scene.Node.fireEvent(Unknown Source)
at javafx.controls/javafx.scene.control.Button.fire(Unknown Source)
at javafx.controls/com.sun.javafx.scene.control.behavior.ButtonBehavior.mouseReleased(Unknown Source)
at javafx.controls/com.sun.javafx.scene.control.inputmap.InputMap.handle(Unknown Source)
at javafx.base/com.sun.javafx.event.CompositeEventHandler$NormalEventHandlerRecord.handleBubblingEvent(Unknow at javafx.base/com.sun.javafx.event.CompositeEventHandler.dispatchBubblingEvent(Unknown Source)
at javafx.base/com.sun.javafx.event.EventHandlerManager.dispatchBubblingEvent(Unknown Source)
at javafx.base/com.sun.javafx.event.EventHandlerManager.dispatchBubblingEvent(Unknown Source)
at javafx.base/com.sun.javafx.event.CompositeEventDispatcher.dispatchBubblingEvent(Unknown Source) at javafx.base/com.sun.javafx.event.BasicEventDispatcher.dispatchEvent(Unknown Source)
at javafx.base/com.sun.javafx.event.EventDispatchChainImpl.dispatchEvent(Unknown Source)
at javafx.base/com.sun.javafx.event.BasicEventDispatcher.dispatchEvent(Unknown Source)
at javafx.base/com.sun.javafx.event.EventDispatchChainImpl.dispatchEvent(Unknown Source) at javafx.base/com.sun.javafx.event.BasicEventDispatcher.dispatchEvent(Unknown Source) at javafx.base/com.sun.javafx.event.EventDispatchChainImpl.dispatchEvent(Unknown Source) at javafx.base/com.sun.javafx.event.BasicEventDispatcher.dispatchEvent(Unknown Source) at javafx.base/com.sun.javafx.event.EventDispatchChainImpl.dispatchEvent(Unknown Source) at javafx.base/com.sun.javafx.event.BasicEventDispatcher.dispatchEvent(Unknown Source) at javafx.base/com.sun.javafx.event.EventDispatchChainImpl.dispatchEvent(Unknown Source) at javafx.base/com.sun.javafx.event.BasicEventDispatcher.dispatchEvent(Unknown Source) at javafx.base/com.sun.javafx.event.EventDispatchChainImpl.dispatchEvent(Unknown Source) at javafx.base/com.sun.javafx.event.EventUtil.fireEventImpl(Unknown Source)
at javafx.base/com.sun.javafx.event.EventUtil.fireEvent(Unknown Source)
at javafx.base/javafx.event.Event.fireEvent(Unknown Source)
at javafx.graphics/javafx.scene.Scene$MouseHandler.process(Unknown Source)
at javafx.graphics/javafx.scene.Scene.processMouseEvent(Unknown Source)
at javafx.graphics/javafx.scene.Scene$ScenePeerListener.mouseEvent(Unknown Source)
at javafx.graphics/com.sun.javafx.tk.quantum.GlassViewEventHandler$MouseEventNotification.run(Unknown Source at javafx.graphics/com.sun.javafx.tk.quantum.GlassViewEventHandler$MouseEventNotification.run(Unknown Source at java.base/java.security.AccessController.doPrivileged(Native Method)
at javafx.graphics/com.sun.javafx.tk.quantum.GlassViewEventHandler.lambda$handleMouseEvent$2(Unknown Source) at javafx.graphics/com.sun.javafx.tk.quantum.QuantumToolkit.runWithoutRenderLock(Unknown Source)
at javafx.graphics/com.sun.javafx.tk.quantum.GlassViewEventHandler.handleMouseEvent(Unknown Source)
at javafx.graphics/com.sun.glass.ui.View.handleMouseEvent(Unknown Source)
at javafx.graphics/com.sun.glass.ui.View.notifyMouse(Unknown Source)
at javafx.graphics/com.sun.glass.ui.win.WinApplication._runLoop(Native Method)
at javafx.graphics/com.sun.glass.ui.win.WinApplication.lambda$runLoop$3(Unknown Source) at java.base/java.lang.Thread.run(Unknown Source)
[INFO] Fri May 15 21:24:20 MSK 2020 Load an scene ./src/main/resources/PID_KALMAN/pid_settings.fxml style type: UTI [INFO] Fri May 15 21:24:20 MSK 2020 Open an gui EXPORT TO : log.txt
[INFO] Fri May 15 21:24:20 MSK 2020 Run an P.I.D Setting EXPORT TO : log.txt
Intergating...
It is a small module
java.io.FileNotFoundException: null\_01_DroneRelese\_01_DroneRelese.ino (Системе не удается найти указанный путь) at java.base/java.io.FileInputStream.open0(Native Method) at java.base/java.io.FileInputStream.open(Unknown Source) at java.base/java.io.FileInputStream.<init>(Unknown Source)
at java.base/java.io.FileInputStream.<init>(Unknown Source)
at java.base/java.io.FileReader.<init>(Unknown Source)
at Electrics.Eagles.Setup.Studio.main/app.API.Modules.Intepeter.ReadValues.read_config_as_array(Unknown Sour at Electrics.Eagles.Setup.Studio.main/app.API.ScrollVBox.ScrollingVBox$2.handle(Unknown Source)
at Electrics.Eagles.Setup.Studio.main/app.API.ScrollVBox.ScrollingVBox$2.handle(Unknown Source)
at javafx.base/com.sun.javafx.event.CompositeEventHandler.dispatchBubblingEvent(Unknown Source)
at javafx.base/com.sun.javafx.event.EventHandlerManager.dispatchBubblingEvent(Unknown Source)
at javafx.base/com.sun.javafx.event.EventHandlerManager.dispatchBubblingEvent(Unknown Source)
at javafx.base/com.sun.javafx.event.CompositeEventDispatcher.dispatchBubblingEvent(Unknown Source) at javafx.base/com.sun.javafx.event.BasicEventDispatcher.dispatchEvent(Unknown Source)
at javafx.base/com.sun.javafx.event.EventDispatchChainImpl.dispatchEvent(Unknown Source)
at javafx.base/com.sun.javafx.event.BasicEventDispatcher.dispatchEvent(Unknown Source)
at javafx.base/com.sun.javafx.event.EventDispatchChainImpl.dispatchEvent(Unknown Source) at javafx.base/com.sun.javafx.event.BasicEventDispatcher.dispatchEvent(Unknown Source) at javafx.base/com.sun.javafx.event.EventDispatchChainImpl.dispatchEvent(Unknown Source) at javafx.base/com.sun.javafx.event.BasicEventDispatcher.dispatchEvent(Unknown Source) at javafx.base/com.sun.javafx.event.EventDispatchChainImpl.dispatchEvent(Unknown Source) at javafx.base/com.sun.javafx.event.BasicEventDispatcher.dispatchEvent(Unknown Source) at javafx.base/com.sun.javafx.event.EventDispatchChainImpl.dispatchEvent(Unknown Source) at javafx.base/com.sun.javafx.event.BasicEventDispatcher.dispatchEvent(Unknown Source) at javafx.base/com.sun.javafx.event.EventDispatchChainImpl.dispatchEvent(Unknown Source) at javafx.base/com.sun.javafx.event.EventUtil.fireEventImpl(Unknown Source)
at javafx.base/com.sun.javafx.event.EventUtil.fireEvent(Unknown Source)
at javafx.base/javafx.event.Event.fireEvent(Unknown Source)
at javafx.graphics/javafx.scene.Node.fireEvent(Unknown Source)
at javafx.controls/javafx.scene.control.Button.fire(Unknown Source)
at javafx.controls/com.sun.javafx.scene.control.behavior.ButtonBehavior.mouseReleased(Unknown Source)
at javafx.controls/com.sun.javafx.scene.control.inputmap.InputMap.handle(Unknown Source)
at javafx.base/com.sun.javafx.event.CompositeEventHandler$NormalEventHandlerRecord.handleBubblingEvent(Unknow at javafx.base/com.sun.javafx.event.CompositeEventHandler.dispatchBubblingEvent(Unknown Source)
at javafx.base/com.sun.javafx.event.EventHandlerManager.dispatchBubblingEvent(Unknown Source)
at javafx.base/com.sun.javafx.event.EventHandlerManager.dispatchBubblingEvent(Unknown Source)
at javafx.base/com.sun.javafx.event.CompositeEventDispatcher.dispatchBubblingEvent(Unknown Source) at javafx.base/com.sun.javafx.event.BasicEventDispatcher.dispatchEvent(Unknown Source)
at javafx.base/com.sun.javafx.event.EventDispatchChainImpl.dispatchEvent(Unknown Source)
at javafx.base/com.sun.javafx.event.BasicEventDispatcher.dispatchEvent(Unknown Source)
at javafx.base/com.sun.javafx.event.EventDispatchChainImpl.dispatchEvent(Unknown Source) at javafx.base/com.sun.javafx.event.BasicEventDispatcher.dispatchEvent(Unknown Source) at javafx.base/com.sun.javafx.event.EventDispatchChainImpl.dispatchEvent(Unknown Source) at javafx.base/com.sun.javafx.event.BasicEventDispatcher.dispatchEvent(Unknown Source) at javafx.base/com.sun.javafx.event.EventDispatchChainImpl.dispatchEvent(Unknown Source) at javafx.base/com.sun.javafx.event.BasicEventDispatcher.dispatchEvent(Unknown Source) at javafx.base/com.sun.javafx.event.EventDispatchChainImpl.dispatchEvent(Unknown Source) at javafx.base/com.sun.javafx.event.BasicEventDispatcher.dispatchEvent(Unknown Source) at javafx.base/com.sun.javafx.event.EventDispatchChainImpl.dispatchEvent(Unknown Source) at javafx.base/com.sun.javafx.event.EventUtil.fireEventImpl(Unknown Source)
at javafx.base/com.sun.javafx.event.EventUtil.fireEvent(Unknown Source)
at javafx.base/javafx.event.Event.fireEvent(Unknown Source)
at javafx.graphics/javafx.scene.Scene$MouseHandler.process(Unknown Source)
at javafx.graphics/javafx.scene.Scene.processMouseEvent(Unknown Source)
at javafx.graphics/javafx.scene.Scene$ScenePeerListener.mouseEvent(Unknown Source)
at javafx.graphics/com.sun.javafx.tk.quantum.GlassViewEventHandler$MouseEventNotification.run(Unknown Source at javafx.graphics/com.sun.javafx.tk.quantum.GlassViewEventHandler$MouseEventNotification.run(Unknown Source at java.base/java.security.AccessController.doPrivileged(Native Method)
at javafx.graphics/com.sun.javafx.tk.quantum.GlassViewEventHandler.lambda$handleMouseEvent$2(Unknown Source) at javafx.graphics/com.sun.javafx.tk.quantum.QuantumToolkit.runWithoutRenderLock(Unknown Source)
at javafx.graphics/com.sun.javafx.tk.quantum.GlassViewEventHandler.handleMouseEvent(Unknown Source)
at javafx.graphics/com.sun.glass.ui.View.handleMouseEvent(Unknown Source)
at javafx.graphics/com.sun.glass.ui.View.notifyMouse(Unknown Source)
at javafx.graphics/com.sun.glass.ui.win.WinApplication._runLoop(Native Method)
at javafx.graphics/com.sun.glass.ui.win.WinApplication.lambda$runLoop$3(Unknown Source) at java.base/java.lang.Thread.run(Unknown Source)

## edited by alex5250

misha-dig (https://github.com/misha-dig) added the | bug (https://github.com/alex5250/ElectricsEaglesStudio/labels/bug) | label on 15 May

## alex5250 (https://github.com/alex5250) commented on 15 May

There should be a warring dialog asking to run Wizard.

## alex5250 (https://github.com/alex5250) commented on 26 May •

## Fixed adding a warring message . #bug-fix-LQY7JCYQF

## edited

## alex5250 (https://github.com/alex5250) closed this on 26 May

Remember, contributions to this repository should follow our GitHub Community Guidelines. (https://docs.github.com/articles/github-community-guidelines)

## Leave a comment

## Choose Files No file chosen

Attach files by dragging & dropping, selecting or pasting them.

## Reopen issue Comment

Assignees

Labels

bug (https://github.com/alex5250/ElectricsEaglesStudio/labels/bug)

Projects

Milestone

Linked pull requests

You’re receiving notifications because you’re watching this repository.

Notifications | Customize

Unsubscribe

© 2020 GitHub, Inc. | Terms (https://github.com/site/terms) | Privacy (https://github.com/site/privacy) | Security (https://github.com/security) | Status (https://githubstatus.com/) | Help (https://docs.github.com/) | Contact GitHub (https://github.com/contact) | Pricing (https://github.com/pricing) | API (https://docs.github.com/) | Training (https://services.github.com/) | Blog (https://github.blog/) | About (https://github.com/about)
Write | Preview
Closed | Cannot intergrate to this drone configuration #14 (https://github.com/pulls) misha-dig (https://github.com/misha-dig) opened this issue on 15 May · 2 comments (https://github.com/pulls)

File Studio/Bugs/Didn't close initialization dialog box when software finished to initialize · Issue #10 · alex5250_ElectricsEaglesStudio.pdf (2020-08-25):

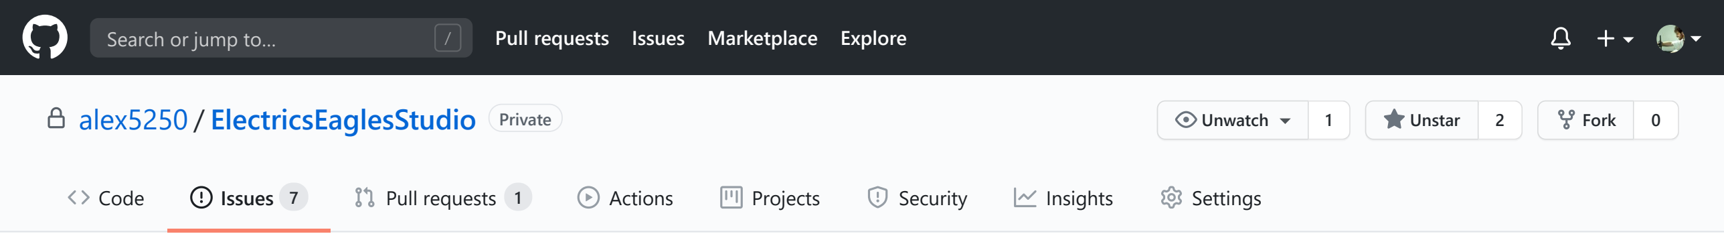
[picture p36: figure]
Code; Issues; Pull requests; Actions; Projects; Security; Insights; Settings; Search or jump to…; Pull requests Issues Marketplace Explore; Unwatch; Unstar; Fork

alex5250 (https://github.com/alex5250) / ElectricsEaglesStudio (https://github.com/alex5250/ElectricsEaglesStudio) Private

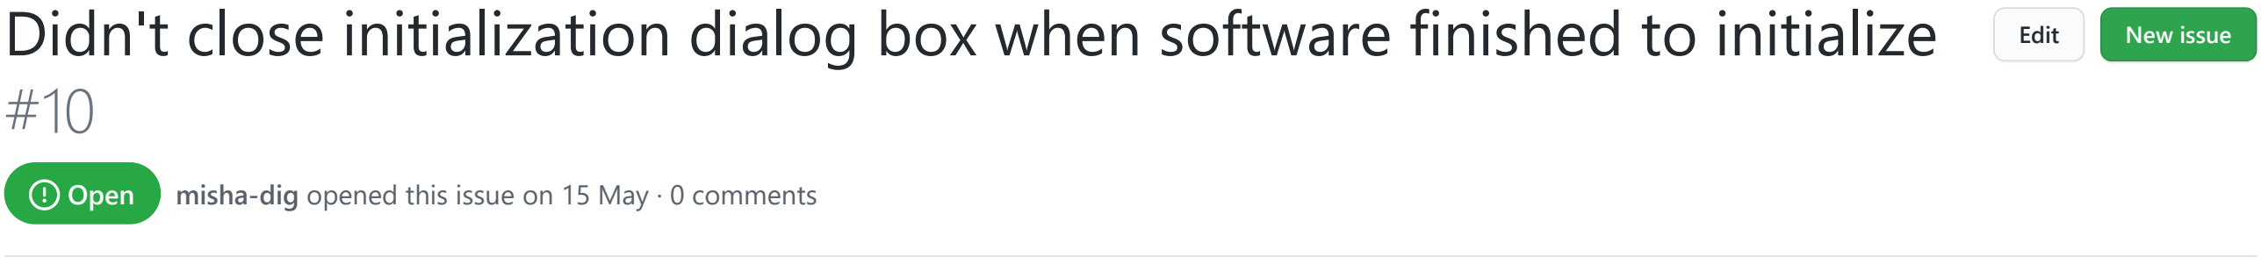
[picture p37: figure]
Edit; New issue

# Didn't close initialization dialog box when software finished to initialize

Open misha-dig (https://github.com/misha-dig) opened this issue on 15 May · 0 comments

No one—assign yourself

None yet

No milestone

Successfully merging a pull request may close this issue.
None yet

### 1 participant

Lock conversation

Pin issue

Transfer issue

Delete issue

misha-dig (https://github.com/misha-dig) commented on 15 May

log.txt (https://github.com/alex5250/ElectricsEaglesStudio/files/4635907/log.txt)

java
[INFO] Fri May 15 19:53:15 MSK 2020 Found boards[Ljava.lang.String;@4ca64d83 EXPORT TO : log.txt
[INFO] Fri May 15 19:53:18 MSK 2020 Python is found EXPORT TO : log.txt
[ERROR] Fri May 15 19:53:18 MSK 2020 Python is found EXPORT TO : log.txt
[INFO] Fri May 15 19:53:18 MSK 2020 Load an scene ./src/main/resources/main_window.fxml style type: DECORATED EXPORT TO : log.txt
0.0
525.0
494.0
It is a small module
[INFO] Fri May 15 19:53:21 MSK 2020 Open an gui EXPORT TO : log.txt
MLANG CONFIG INTEPETER VERISON: 1.0.243532 C:\Users\Programmer\Downloads\ElectricsEaglesStudio\bin\src\main\resources\Wirzard.FXML
[INFO] Fri May 15 19:55:46 MSK 2020 Load an scene C:\Users\Programmer\Downloads\ElectricsEaglesStudio\bin\src\main\resources\Wirzard.FXML\step_1.fxml style type: EXPORT TO : log.txt
[INFO] Fri May 15 19:55:46 MSK 2020 Open an gui EXPORT TO : log.txt
[INFO] Fri May 15 19:55:46 MSK 2020 Run an app.Wirzard EXPORT TO : log.txt
[INFO] Fri May 15 19:58:39 MSK 2020 Load an scene ./src/main/resources/PID_KALMAN/pid_settings.fxml style type: UTILITY EXPORT TO : log.txt
[INFO] Fri May 15 19:58:39 MSK 2020 Open an gui EXPORT TO : log.txt
[INFO] Fri May 15 19:58:39 MSK 2020 Run an P.I.D Setting EXPORT TO : log.txt
misha-dig (https://github.com/misha-dig) added the | bug (https://github.com/alex5250/ElectricsEaglesStudio/labels/bug) | label on 15 May

Remember, contributions to this repository should follow our GitHub Community Guidelines. (https://docs.github.com/articles/github-community-guidelines)

Leave a comment

Choose Files No file chosen

Attach files by dragging & dropping, selecting or pasting them.

Close issue Comment

Assignees

Labels

bug (https://github.com/alex5250/ElectricsEaglesStudio/labels/bug)

Projects

Milestone

Linked pull requests

You’re receiving notifications because you’re watching this repository.

Notifications | Customize

Unsubscribe

© 2020 GitHub, Inc. | Terms (https://github.com/site/terms) | Privacy (https://github.com/site/privacy) | Security (https://github.com/security) | Status (https://githubstatus.com/) | Help (https://docs.github.com/) | Contact GitHub (https://github.com/contact) | Pricing (https://github.com/pricing) | API (https://docs.github.com/) | Training (https://services.github.com/) | Blog (https://github.blog/) | About (https://github.com/about)
Write | Preview

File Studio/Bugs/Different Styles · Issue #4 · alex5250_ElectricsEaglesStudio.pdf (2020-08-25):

alex5250 (https://github.com/alex5250) / ElectricsEaglesStudio (https://github.com/alex5250/ElectricsEaglesStudio) Private

Code (https://github.com/alex5250/ElectricsEaglesStudio) | Issues | 7 (https://github.com/alex5250/ElectricsEaglesStudio/issues) | Pull requests | 1 (https://github.com/alex5250/ElectricsEaglesStudio/pulls) | Actions (https://github.com/alex5250/ElectricsEaglesStudio/actions) | Projects (https://github.com/alex5250/ElectricsEaglesStudio/projects) | Security (https://github.com/alex5250/ElectricsEaglesStudio/security) | Insights (https://github.com/alex5250/ElectricsEaglesStudio/network/dependencies) | Settings (https://github.com/alex5250/ElectricsEaglesStudio/settings)

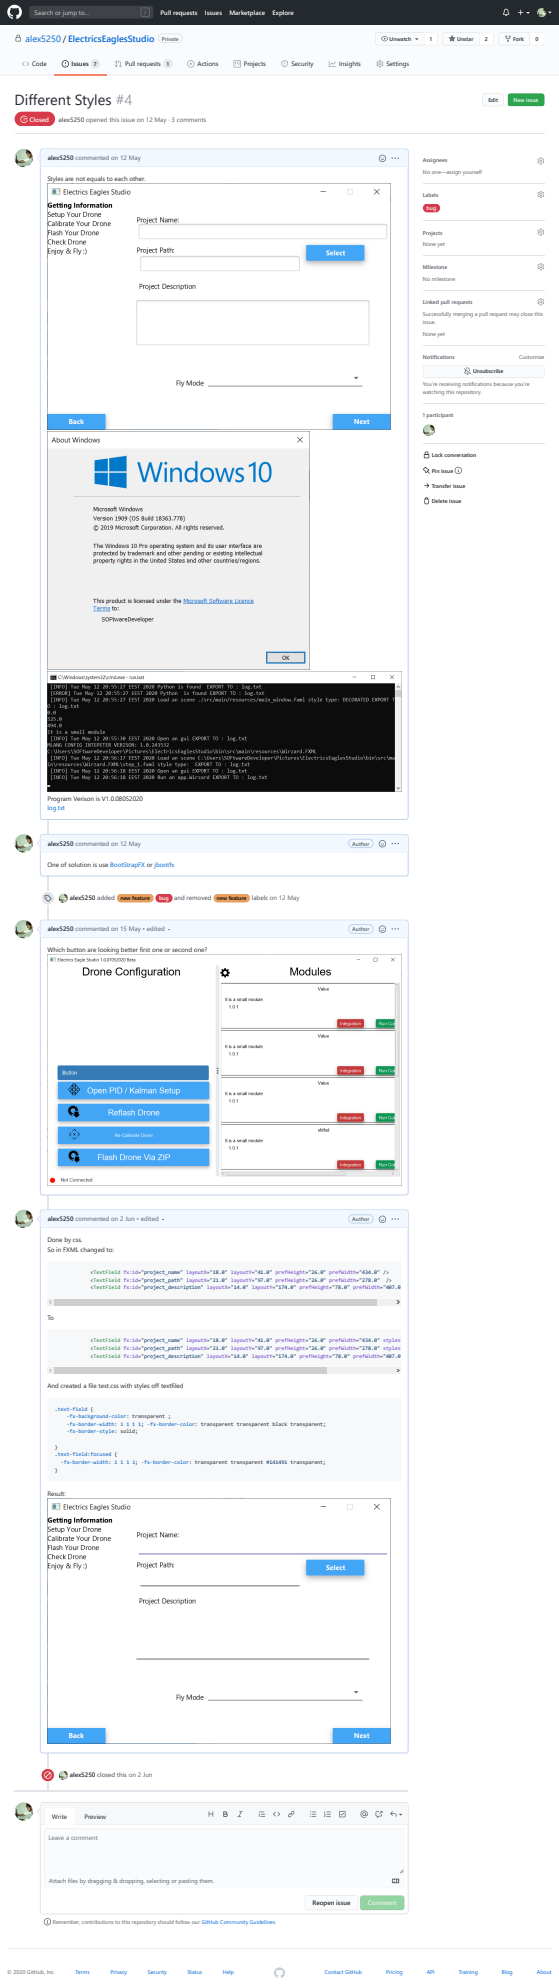
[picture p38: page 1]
Different Styles #4; Closed; alex5250 opened this issue on 12 May · 3 comments; None yet; No milestone; 1 participant; Lock conversation; Pin issue; Transfer issue; Delete issue; Search or jump to…; Pull requests Issues Marketplace Explore; Unwatch; Unstar; Fork; Edit; New issue; Author; alex5250 added; new feature; bug; and removed; labels on 12 May; edited; Result:; Leave a comment; Reopen issue; Comment; Labels; Projects; Milestone; Notifications; Customize; Unsubscribe; © 2020 GitHub, Inc.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

alex5250 (https://github.com/alex5250) commented on 12 May

Assignees
No one—assign yourself

Styles are not equals to each other.

Linked pull requests
Successfully merging a pull request may close this
issue.
None yet

You’re receiving notifications because you’re
watching this repository.

Program Verison is V1.0.08052020
log.txt (https://github.com/alex5250/ElectricsEaglesStudio/files/4617570/log.txt)

One of solution is use BootStrapFX (https://github.com/kordamp/bootstrapfx) or jbootfx (https://github.com/mlayah/material-dashboard-fx)

alex5250 (https://github.com/alex5250) commented on 15 May •

Which button are looking better first one or second one?

alex5250 (https://github.com/alex5250) commented on 2 Jun •

Done by css.
So in FXML changed to:

<TextField fx:id="project_name" layoutX="18.0" layoutY="41.0" prefHeight="26.0" prefWidth="434.0" />
<TextField fx:id="project_path" layoutX="21.0" layoutY="97.0" prefHeight="26.0" prefWidth="278.0" />
<TextField fx:id="project_description" layoutX="14.0" layoutY="174.0" prefHeight="78.0" prefWidth="407.0

<TextField fx:id="project_name" layoutX="18.0" layoutY="41.0" prefHeight="26.0" prefWidth="434.0" styles
<TextField fx:id="project_path" layoutX="21.0" layoutY="97.0" prefHeight="26.0" prefWidth="278.0" styles

And created a file text.css with styles off textfiled

.text-field {
-fx-background-color: transparent ;
-fx-border-width: 1 1 1 1; -fx-border-color: transparent transparent black transparent;
-fx-border-style: solid;

.text-field:focused {
-fx-border-width: 1 1 1 1; -fx-border-color: transparent transparent #141491 transparent;

alex5250 (https://github.com/alex5250) closed this on 2 Jun

Attach files by dragging & dropping, selecting or pasting them.
Choose Files No file chosen

Remember, contributions to this repository should follow our GitHub Community Guidelines. (https://docs.github.com/articles/github-community-guidelines)

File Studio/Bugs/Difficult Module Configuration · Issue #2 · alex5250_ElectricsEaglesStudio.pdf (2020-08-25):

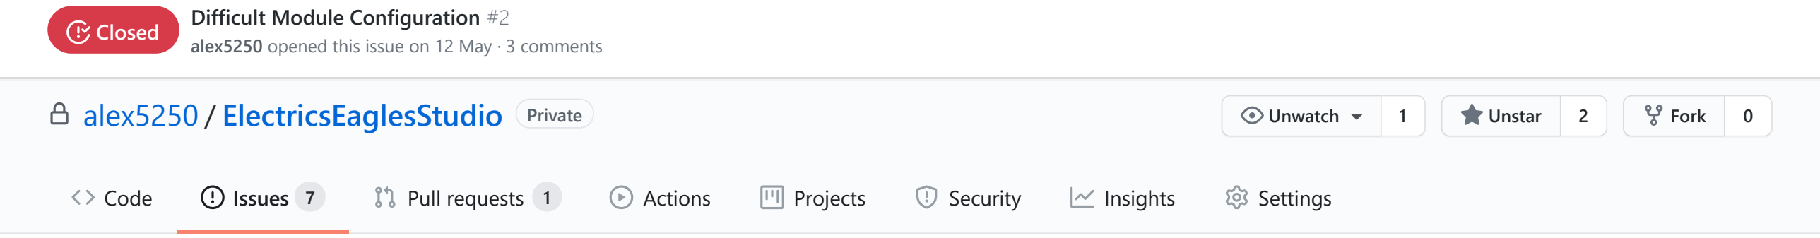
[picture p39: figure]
Code; Issues; Pull requests; Actions; Projects; Security; Insights; Settings; Search or jump to…; Pull requests Issues Marketplace Explore; Unwatch; Unstar; Fork; Closed; Difficult Module Configuration #2

alex5250 (https://github.com/alex5250) / ElectricsEaglesStudio (https://github.com/alex5250/ElectricsEaglesStudio) Private

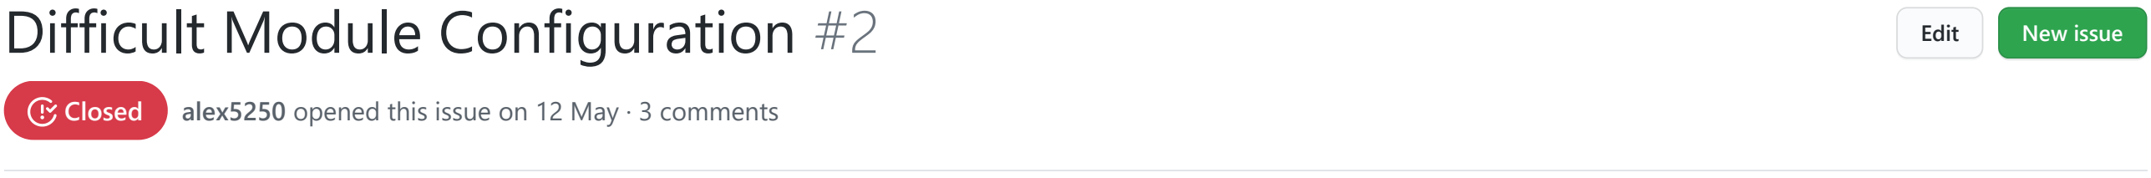
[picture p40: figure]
Difficult Module Configuration #2; Edit; New issue

Closed alex5250 (https://github.com/alex5250) opened this issue on 12 May · 3 comments

No one—assign yourself

None yet

No milestone

Successfully merging a pull request may close this issue.
None yet

### 1 participant

Lock conversation

Pin issue

Transfer issue

Delete issue

alex5250 (https://github.com/alex5250) commented on 12 May •

Now Configuration Module file is complex to setup. Also is unstable work.

__MODULE__CONFIG___

add_to_code{
begin;
add;
include <demo.h>
end;
add_to_code};

run{
run_app,./modules/Demo/configurator/Demo.exe run};

verison{
1.0.1;
verison};

arduino{
arduino:nano;
arduino};

name{
Demo Module
name};

description{
It is a small module
description};

edited

alex5250 (https://github.com/alex5250) commented on 12 May

Solution is use XML/JSON.

Author

alex5250 (https://github.com/alex5250) added the | bug (https://github.com/alex5250/ElectricsEaglesStudio/labels/bug) | label on 12 May

alex5250 (https://github.com/alex5250) commented on 13 May

Json will be beter. (Also not Johnson, (great joke ha-ha-ha ) );

Author

alex5250 (https://github.com/alex5250) commented on 26 May

Fixed on #21 (https://github.com/alex5250/ElectricsEaglesStudio/pull/21) .

Now module setup demo:

{
"name": "Demo",
"description": "Is a small module for checking are all system working", "version": "v1.0.8",
"controller": "arduino:nano",
"tasks": {
"insert": "after_insert:void setup():include <GPS.h>;" },
"run": {
"run": "./configurator/Demo.exe"

}

}

Author

alex5250 (https://github.com/alex5250) closed this on 26 May

Remember, contributions to this repository should follow our GitHub Community Guidelines. (https://docs.github.com/articles/github-community-guidelines)

Leave a comment

Choose Files No file chosen

Attach files by dragging & dropping, selecting or pasting them.

Reopen issue Comment

Assignees

Labels

bug (https://github.com/alex5250/ElectricsEaglesStudio/labels/bug)

Projects

Milestone

Linked pull requests

You’re receiving notifications because you’re watching this repository.

Notifications | Customize

Unsubscribe

© 2020 GitHub, Inc. | Terms (https://github.com/site/terms) | Privacy (https://github.com/site/privacy) | Security (https://github.com/security) | Status (https://githubstatus.com/) | Help (https://docs.github.com/) | Contact GitHub (https://github.com/contact) | Pricing (https://github.com/pricing) | API (https://docs.github.com/) | Training (https://services.github.com/) | Blog (https://github.blog/) | About (https://github.com/about)
Write | Preview

alex5250 (https://github.com/alex5250) opened this issue on 12 May · 3 comments (https://github.com/pulls)

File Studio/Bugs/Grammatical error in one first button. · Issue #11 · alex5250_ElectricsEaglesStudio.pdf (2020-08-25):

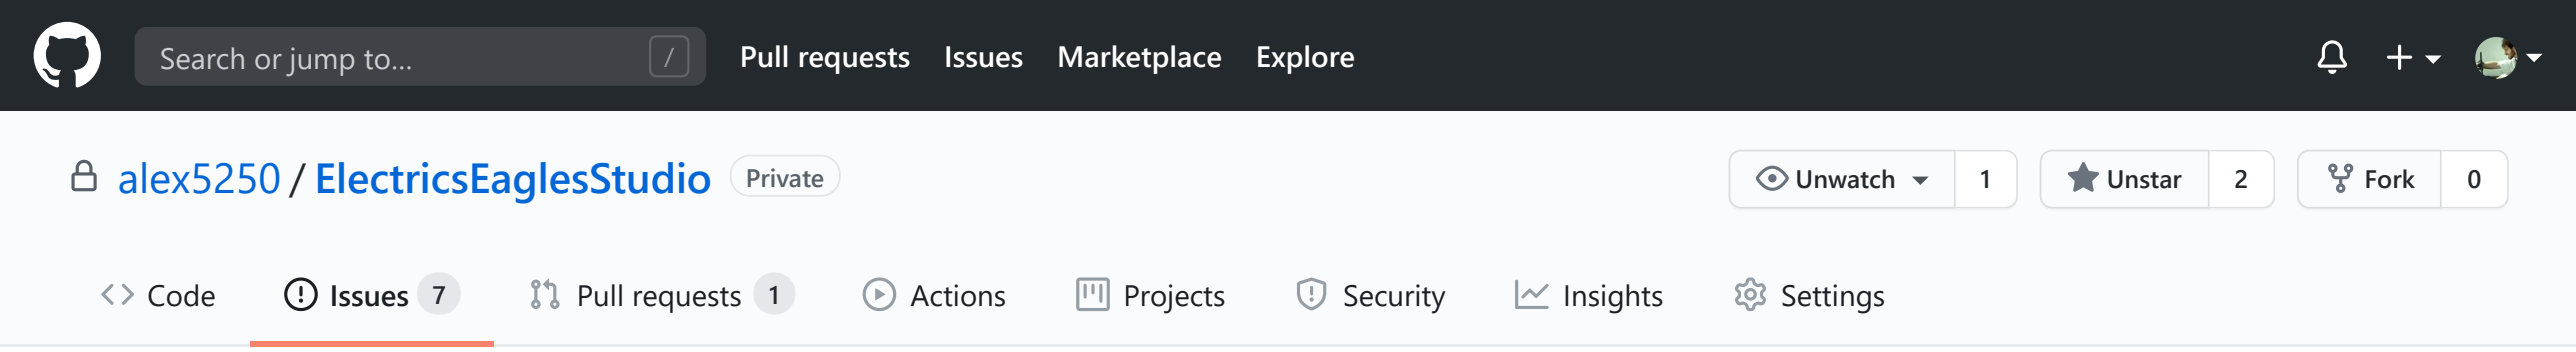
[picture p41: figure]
Code; Issues; Pull requests; Actions; Projects; Security; Insights; Settings; Search or jump to…; Pull requests Issues Marketplace Explore; Unwatch; Unstar; Fork

alex5250 (https://github.com/alex5250) / ElectricsEaglesStudio (https://github.com/alex5250/ElectricsEaglesStudio) Private

# Grammatical error in one first button. #11

Closed misha-dig (https://github.com/misha-dig) opened this issue on 15 May · 4 comments

No one—assign yourself

None yet

No milestone

Successfully merging a pull request may close this issue.
None yet

### 3 participants

Lock conversation

Pin issue

Transfer issue

Delete issue

Edit New issue (https://github.com/alex5250/ElectricsEaglesStudio/issues/new/choose)

misha-dig (https://github.com/misha-dig) commented on 15 May

Please correct sentence in first button of main application.
Instead of 'Open Configurator app.Wizard' to 'Open Configurator application wizard'.
Additionally, all buttons used uppercase letter in first each word in sentence, which some words haven't name of sciencelist, place, company.
E.g. Reflash Drone need correct to Reflash drone
misha-dig (https://github.com/misha-dig) added the | grammar (https://github.com/alex5250/ElectricsEaglesStudio/labels/grammar) | label on 15 May

alex5250 (https://github.com/alex5250) commented on 15 May

@DekosZero (https://github.com/DekosZero) What you think? Also we need ask Mr Carrion.

alex5250 (https://github.com/alex5250) commented on 15 May

I think is better Open Configuration Wizard Also Re-flash Drone

DekosZero (https://github.com/DekosZero) commented on 15 May

@DekosZero (https://github.com/DekosZero) What you think? Also we need ask Mr Carrion.

i think it is needless

I think is better Open Configuration Wizard
Also *Re-flash Drone
okay
true

DekosZero (https://github.com/DekosZero) assigned DekosZero (https://github.com/DekosZero) and unassigned DekosZero (https://github.com/DekosZero) on 15 May

alex5250 (https://github.com/alex5250) commented on 3 Jun

Just changed to Open Configuration

alex5250 (https://github.com/alex5250) closed this on 3 Jun

Remember, contributions to this repository should follow our GitHub Community Guidelines. (https://docs.github.com/articles/github-community-guidelines)

Leave a comment

Choose Files No file chosen

Attach files by dragging & dropping, selecting or pasting them.

Reopen issue Comment

Assignees

Labels

grammar (https://github.com/alex5250/ElectricsEaglesStudio/labels/grammar)

Projects

Milestone

Linked pull requests

You’re receiving notifications because you’re watching this repository.

Notifications | Customize

Unsubscribe

© 2020 GitHub, Inc. | Terms (https://github.com/site/terms) | Privacy (https://github.com/site/privacy) | Security (https://github.com/security) | Status (https://githubstatus.com/) | Help (https://docs.github.com/) | Contact GitHub (https://github.com/contact) | Pricing (https://github.com/pricing) | API (https://docs.github.com/) | Training (https://services.github.com/) | Blog (https://github.blog/) | About (https://github.com/about)
Write | Preview

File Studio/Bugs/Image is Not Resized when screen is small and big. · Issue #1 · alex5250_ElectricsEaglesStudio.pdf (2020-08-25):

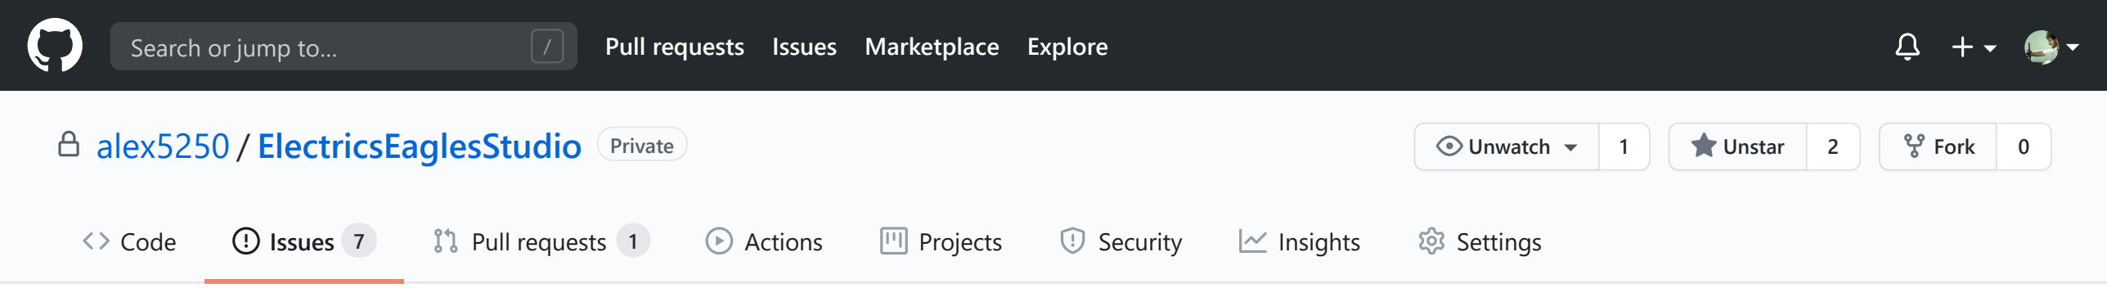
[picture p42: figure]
Code; Issues; Pull requests; Actions; Projects; Security; Insights; Settings; Search or jump to…; Pull requests Issues Marketplace Explore; Unwatch; Unstar; Fork

alex5250 (https://github.com/alex5250) / ElectricsEaglesStudio (https://github.com/alex5250/ElectricsEaglesStudio) Private

# Image is Not Resized when screen is small and big. #1

Open alex5250 (https://github.com/alex5250) opened this issue on 9 May · 0 comments

No one—assign yourself

None yet

No milestone

Successfully merging a pull request may close this issue.
None yet

### 1 participant

Lock conversation

Pin issue

Transfer issue

Delete issue

Edit New issue (https://github.com/alex5250/ElectricsEaglesStudio/issues/new/choose)

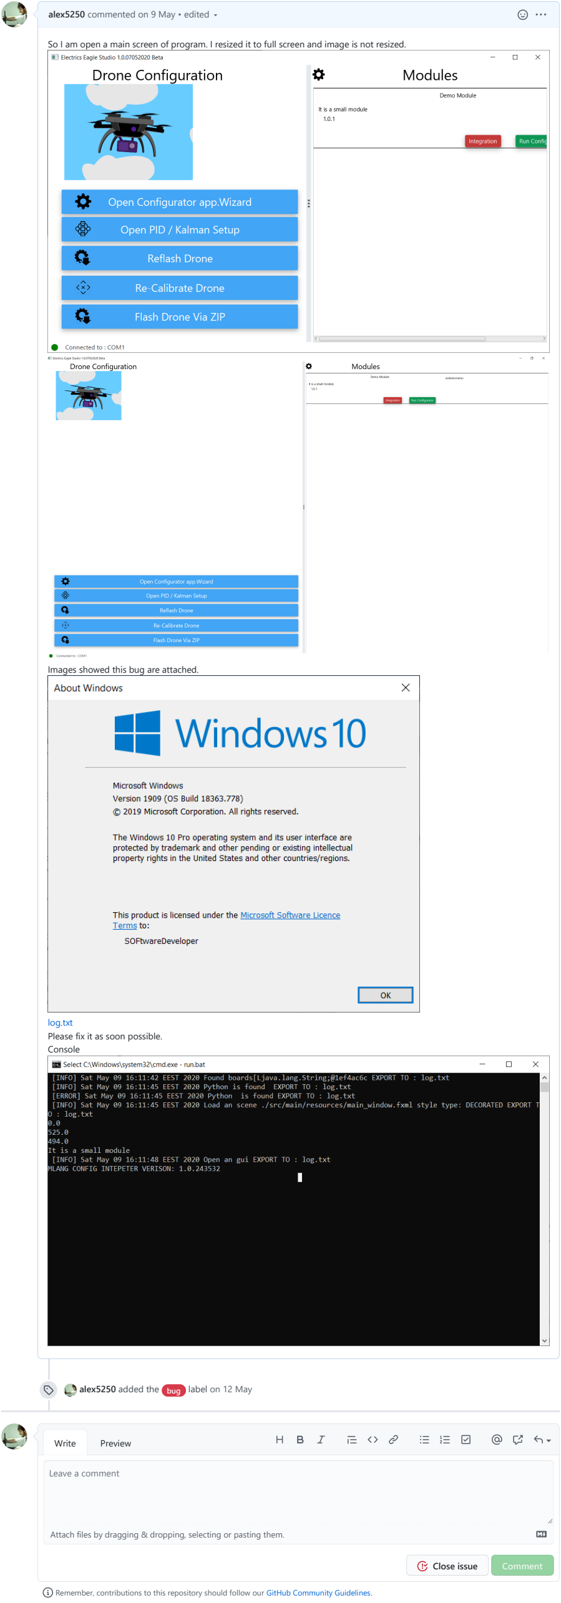
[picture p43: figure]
alex5250 commented on 9 May •; Images showed this bug are attached.; log.txt Please fix it as soon possible. Console; edited; alex5250 added the; bug; label on 12 May; Leave a comment; Choose Files No file chosen; Close issue; Comment; Write; Preview

So I am open a main screen of program. I resized it to full screen and image is not resized.

Remember, contributions to this repository should follow our GitHub Community Guidelines. (https://docs.github.com/articles/github-community-guidelines)

Attach files by dragging & dropping, selecting or pasting them.

Assignees

Labels

bug (https://github.com/alex5250/ElectricsEaglesStudio/labels/bug)

Projects

Milestone

Linked pull requests

You’re receiving notifications because you’re watching this repository.

Notifications | Customize

Unsubscribe

© 2020 GitHub, Inc. | Terms (https://github.com/site/terms) | Privacy (https://github.com/site/privacy) | Security (https://github.com/security) | Status (https://githubstatus.com/) | Help (https://docs.github.com/) | Contact GitHub (https://github.com/contact) | Pricing (https://github.com/pricing) | API (https://docs.github.com/) | Training (https://services.github.com/) | Blog (https://github.blog/) | About (https://github.com/about)

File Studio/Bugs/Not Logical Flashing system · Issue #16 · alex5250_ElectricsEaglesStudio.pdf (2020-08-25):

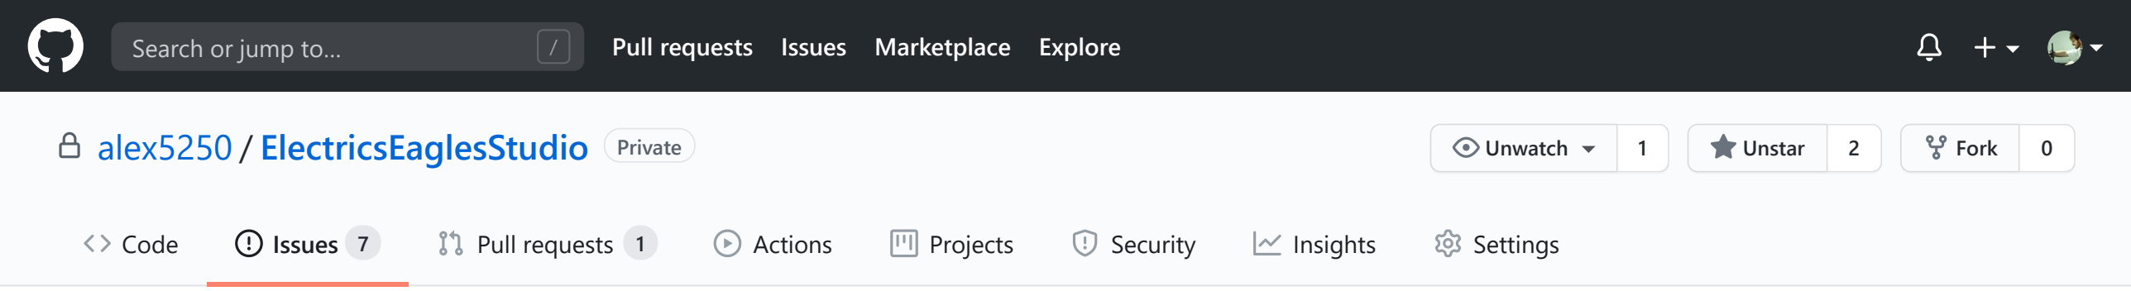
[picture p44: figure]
Code; Issues; Pull requests; Actions; Projects; Security; Insights; Settings; Search or jump to…; Pull requests Issues Marketplace Explore; Unwatch; Unstar; Fork

alex5250 (https://github.com/alex5250) / ElectricsEaglesStudio (https://github.com/alex5250/ElectricsEaglesStudio) Private

# Not Logical Flashing system #16

Open alex5250 (https://github.com/alex5250) opened this issue on 16 May · 2 comments

No one—assign yourself

None yet

No milestone

Successfully merging a pull request may close this issue.

None yet

### 1 participant

Lock conversation

Pin issue

Transfer issue

Delete issue

Edit New issue (https://github.com/alex5250/ElectricsEaglesStudio/issues/new/choose)

alex5250 (https://github.com/alex5250) commented on 16 May

I set up drone and in before last step I had window with flash button , and where are only one button . 'Flash' I thing it will better to do it in auto mode .

Also same error in Reflash drone. I think everything should work in auto mode

alex5250 (https://github.com/alex5250) commented on 16 May

instad this there are load bar that ask user to wait. It make more sense that this.

Author

alex5250 (https://github.com/alex5250) commented on 4 Jun •

So maked one system on Java Swing . For zip it is

Classinc flash window :

So i think i can remove the zip flasher.

edited | Author

Remember, contributions to this repository should follow our GitHub Community Guidelines. (https://docs.github.com/articles/github-community-guidelines)

Leave a comment

Choose Files No file chosen

Attach files by dragging & dropping, selecting or pasting them.

Close issue Comment

Assignees

Labels
None yet

Projects

Milestone

Linked pull requests

You’re receiving notifications because you’re watching this repository.

Notifications | Customize

Unsubscribe

© 2020 GitHub, Inc. | Terms (https://github.com/site/terms) | Privacy (https://github.com/site/privacy) | Security (https://github.com/security) | Status (https://githubstatus.com/) | Help (https://docs.github.com/) | Contact GitHub (https://github.com/contact) | Pricing (https://github.com/pricing) | API (https://docs.github.com/) | Training (https://services.github.com/) | Blog (https://github.blog/) | About (https://github.com/about)
Write | Preview

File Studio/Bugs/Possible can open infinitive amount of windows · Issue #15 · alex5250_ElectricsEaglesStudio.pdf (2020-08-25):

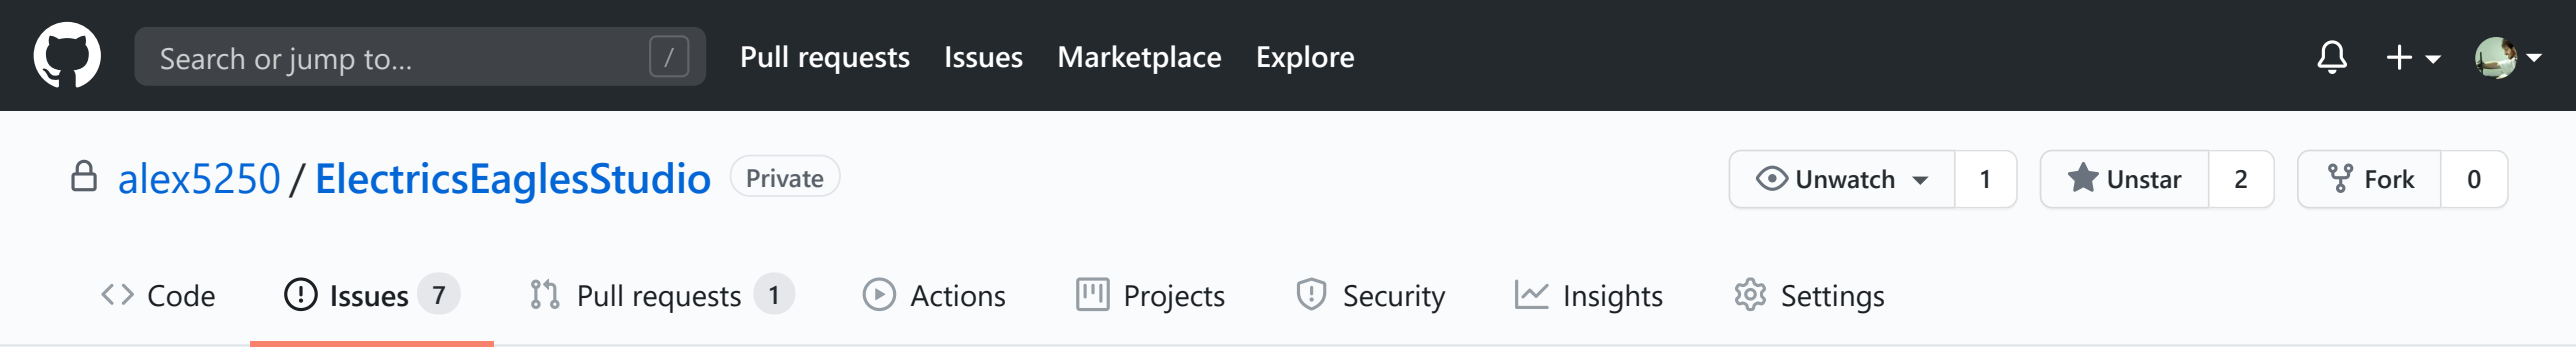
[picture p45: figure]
Code; Issues; Pull requests; Actions; Projects; Security; Insights; Settings; Search or jump to…; Pull requests Issues Marketplace Explore; Unwatch; Unstar; Fork

alex5250 (https://github.com/alex5250) / ElectricsEaglesStudio (https://github.com/alex5250/ElectricsEaglesStudio) Private

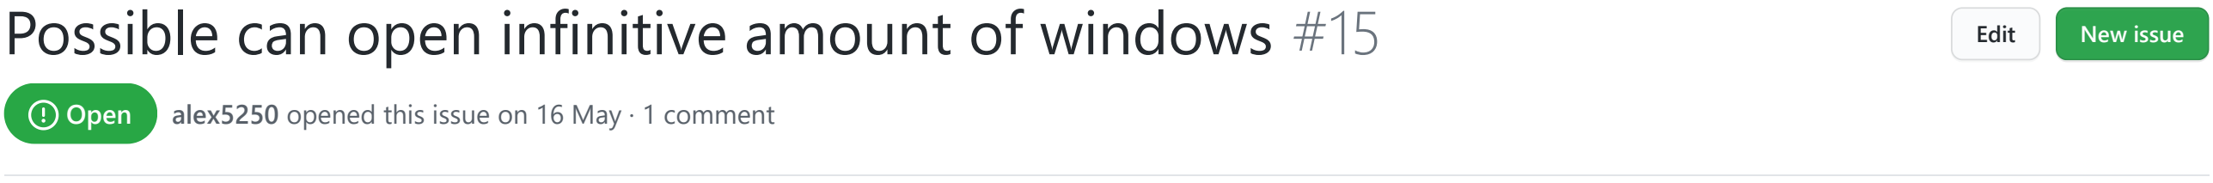
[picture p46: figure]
Edit; New issue

# Possible can open infinitive amount of windows #15

Open alex5250 (https://github.com/alex5250) opened this issue on 16 May · 1 comment

No one—assign yourself

None yet

No milestone

Successfully merging a pull request may close this issue.
None yet

### 1 participant

Lock conversation

Pin issue

Transfer issue

Delete issue

alex5250 (https://github.com/alex5250) commented on 16 May

I open , app and press each button some times. After hiding app i had surprise.

alex5250 (https://github.com/alex5250) changed the title I can open infinitive amout of windows Possible can open infinitive amount of windows on 16 May

alex5250 (https://github.com/alex5250) added the | bug (https://github.com/alex5250/ElectricsEaglesStudio/labels/bug) | label on 16 May

alex5250 (https://github.com/alex5250) commented on 26 May

Is much difficult than I think.
Does somebody has any idea anout how i can block open windows infinitive times? @misha-dig (https://github.com/misha-dig) @DekosZero (https://github.com/DekosZero) I don't need code I need only some advices for algoritm.

Author

Remember, contributions to this repository should follow our GitHub Community Guidelines. (https://docs.github.com/articles/github-community-guidelines)

Leave a comment

Choose Files No file chosen

Attach files by dragging & dropping, selecting or pasting them.

Close issue Comment

Assignees

Labels

bug (https://github.com/alex5250/ElectricsEaglesStudio/labels/bug)

Projects

Milestone

Linked pull requests

You’re receiving notifications because you’re watching this repository.

Notifications | Customize

Unsubscribe

© 2020 GitHub, Inc. | Terms (https://github.com/site/terms) | Privacy (https://github.com/site/privacy) | Security (https://github.com/security) | Status (https://githubstatus.com/) | Help (https://docs.github.com/) | Contact GitHub (https://github.com/contact) | Pricing (https://github.com/pricing) | API (https://docs.github.com/) | Training (https://services.github.com/) | Blog (https://github.blog/) | About (https://github.com/about)
Write | Preview

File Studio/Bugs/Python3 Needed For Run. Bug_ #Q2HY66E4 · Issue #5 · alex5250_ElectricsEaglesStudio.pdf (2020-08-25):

alex5250 (https://github.com/alex5250) / ElectricsEaglesStudio (https://github.com/alex5250/ElectricsEaglesStudio) Private

# Python3 Needed For Run. Bug: #Q2HY66E4 #5

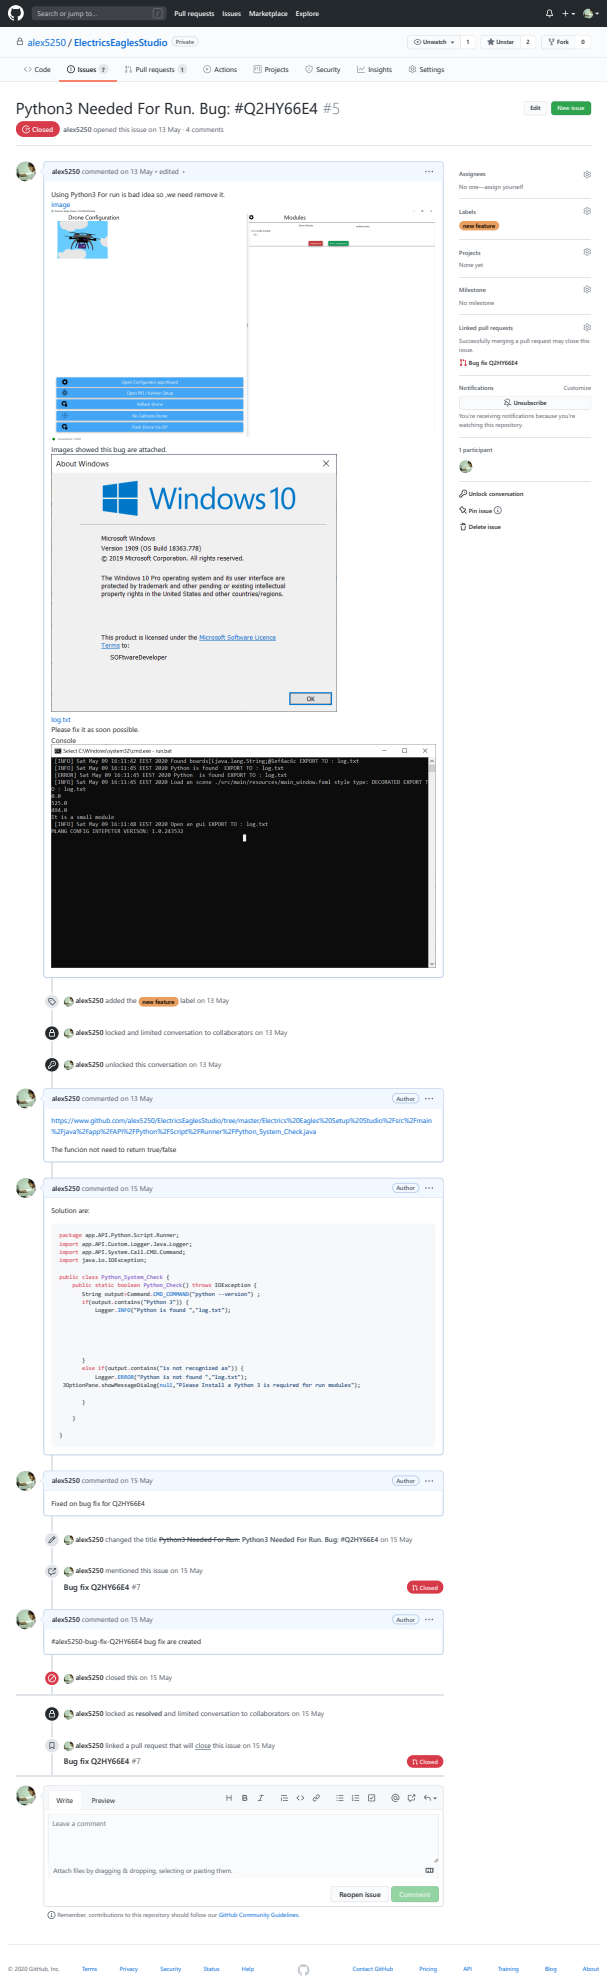
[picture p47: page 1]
Code; Issues; Pull requests; Actions; Projects; Security; Insights; Settings; Closed; alex5250 opened this issue on 13 May · 4 comments; None yet; No milestone; 1 participant; Unlock conversation; Pin issue; Delete issue; Search or jump to…; Pull requests Issues Marketplace Explore; Unwatch; Unstar; Fork; Edit; New issue; edited; alex5250 added the; new feature; label on 13 May; Author; Solution are:; Bug fix Q2HY66E4 #7; alex5250 linked a pull request that will; this issue on 15 May; close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

alex5250 (https://github.com/alex5250) commented on 13 May •

Assignees
No one—assign yourself

Using Python3 For run is bad idea so ,we need remove it.
image (https://user-images.githubusercontent.com/20460747/81474680-cd045780-920f-11ea-9c42-dcc32b2edceb.png)

Linked pull requests
Successfully merging a pull request may close this
issue.
Bug fix Q2HY66E4 (https://github.com/alex5250/ElectricsEaglesStudio/pull/7)

You’re receiving notifications because you’re
watching this repository.

Images showed this bug are attached.

log.txt (https://github.com/alex5250/ElectricsEaglesStudio/files/4603497/log.txt)
Please fix it as soon possible.
Console

alex5250 (https://github.com/alex5250) locked and limited conversation to collaborators on 13 May

alex5250 (https://github.com/alex5250) unlocked this conversation on 13 May

alex5250 (https://github.com/alex5250) commented on 13 May

https://www.github.com/alex5250/ElectricsEaglesStudio/tree/master/Electrics%20Eagles%20Setup%20Studio%2Fsrc%2Fmain
%2Fjava%2Fapp%2FAPI%2FPython%2FScript%2FRunner%2FPython_System_Check.java (https://www.github.com/alex5250/ElectricsEaglesStudio/tree/master/Electrics%20Eagles%20Setup%20Studio%2Fsrc%2Fmain%2Fjava%2Fapp%2FAPI%2FPython%2FScript%2FRunn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)

The funcion not need to return true/false

alex5250 (https://github.com/alex5250) commented on 15 May

package app.API.Python.Script.Runner;
import app.API.Custom.Logger.Java.Logger;
import app.API.System.Call.CMD.Command;
import java.io.IOException;

public class Python_System_Check {
public static boolean Python_Check() throws IOException {
String output=Command.CMD_COMMAND("python --version") ;
if(output.contains("Python 3")) {
Logger.INFO("Python is found ","log.txt");

else if(output.contains("is not recognized as")) {
Logger.ERROR("Python is not found ","log.txt");

JOptionPane.showMessageDialog(null,"Please Install a Python 3 is required for run modules");

Fixed on bug fix for Q2HY66E4

alex5250 (https://github.com/alex5250) changed the title Python3 Needed For Run. Python3 Needed For Run. Bug: #Q2HY66E4 on 15 May

alex5250 (https://github.com/alex5250) mentioned this issue on 15 May

#alex5250-bug-fix-Q2HY66E4 bug fix are created

alex5250 (https://github.com/alex5250) closed this on 15 May

alex5250 (https://github.com/alex5250) locked as resolved and limited conversation to collaborators on 15 May

Attach files by dragging & dropping, selecting or pasting them.
Choose Files No file chosen

Remember, contributions to this repository should follow our GitHub Community Guidelines. (https://docs.github.com/articles/github-community-guidelines)

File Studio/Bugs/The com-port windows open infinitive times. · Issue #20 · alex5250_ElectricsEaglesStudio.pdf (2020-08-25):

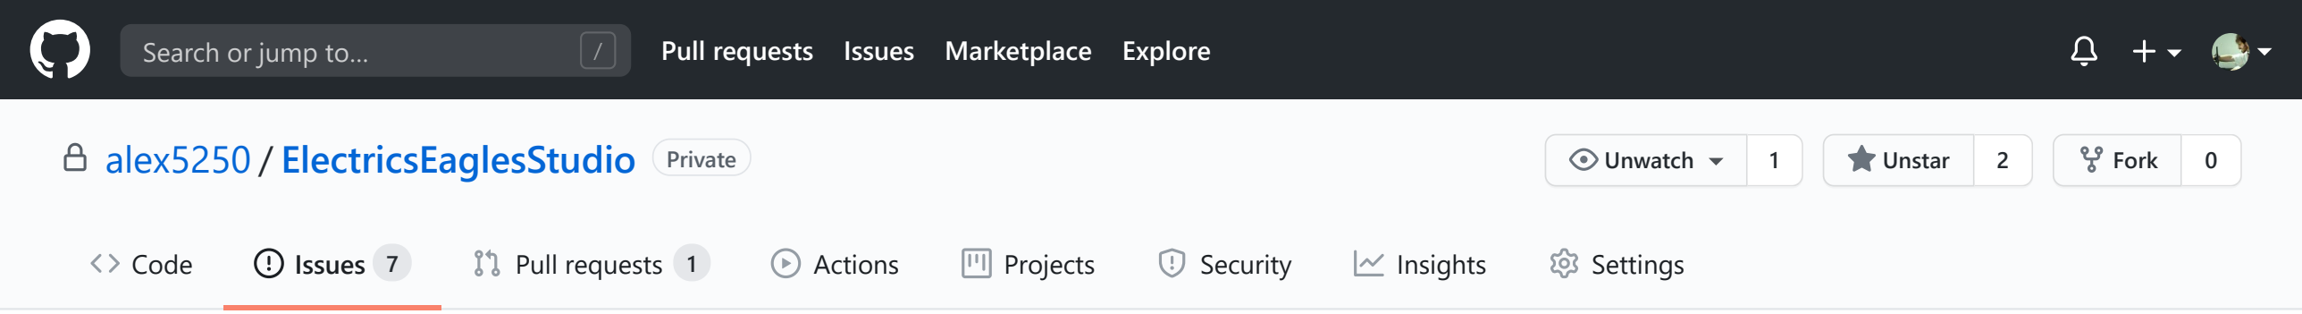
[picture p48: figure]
Unwatch; Unstar; Fork

alex5250 (https://github.com/alex5250) / ElectricsEaglesStudio (https://github.com/alex5250/ElectricsEaglesStudio) Private

Code (https://github.com/alex5250/ElectricsEaglesStudio) | Issues | 7 (https://github.com/alex5250/ElectricsEaglesStudio/issues) | Pull requests | 1 (https://github.com/alex5250/ElectricsEaglesStudio/pulls) | Actions (https://github.com/alex5250/ElectricsEaglesStudio/actions) | Projects (https://github.com/alex5250/ElectricsEaglesStudio/projects) | Security (https://github.com/alex5250/ElectricsEaglesStudio/security) | Insights (https://github.com/alex5250/ElectricsEaglesStudio/network/dependencies) | Settings (https://github.com/alex5250/ElectricsEaglesStudio/settings)

# The com-port windows open infinitive times. #20

## Closed alex5250 (https://github.com/alex5250) opened this issue on 19 May · 2 comments

No one—assign yourself

None yet

No milestone

Successfully merging a pull request may close this issue.

None yet

### 1 participant

Lock conversation

Pin issue

Transfer issue

Delete issue

Search or jump to… | Pull requests (https://github.com/pulls) Issues (https://github.com/issues) Marketplace (https://github.com/marketplace) Explore (https://github.com/explore)
Edit | New issue (https://github.com/alex5250/ElectricsEaglesStudio/issues/new/choose)

## alex5250 (https://github.com/alex5250) commented on 19 May

## 1. I open studio 2. I press a red circle button

3. I hide studio and see this disaster.

V 1.0.0.08052020

## alex5250 (https://github.com/alex5250) commented on 19 May

## log.txt (https://github.com/alex5250/ElectricsEaglesStudio/files/4651346/log.txt) Console log:

[INFO] Tue May 19 15:57:02 BST 2020 Found boards[Ljava.lang.String;@34aa9495 EXPORT TO : log.txt
[INFO] Tue May 19 15:57:04 BST 2020 Python is found EXPORT TO : log.txt
[ERROR] Tue May 19 15:57:04 BST 2020 Python is found EXPORT TO : log.txt
[INFO] Tue May 19 15:57:04 BST 2020 Load an scene ./src/main/resources/main_window.fxml style type: DECORATED EXPORT 0.0
525.0
494.0
It is a small module
[INFO] Tue May 19 15:57:08 BST 2020 Open an gui EXPORT TO : log.txt
MLANG CONFIG INTEPETER VERISON: 1.0.243532
[INFO] Tue May 19 15:57:20 BST 2020 Load an scene ./src/main/resources/ComPort/comport.fxml style type: UTILITY EXPO [INFO] Tue May 19 15:57:20 BST 2020 Open an gui EXPORT TO : log.txt
null
[INFO] Tue May 19 15:57:27 BST 2020 Load an scene ./src/main/resources/ComPort/comport.fxml style type: UTILITY EXPO [INFO] Tue May 19 15:57:28 BST 2020 Open an gui EXPORT TO : log.txt
null
[INFO] Tue May 19 15:57:38 BST 2020 Load an scene ./src/main/resources/ComPort/comport.fxml style type: UTILITY EXPO [INFO] Tue May 19 15:57:38 BST 2020 Open an gui EXPORT TO : log.txt
null
[INFO] Tue May 19 15:57:38 BST 2020 Load an scene ./src/main/resources/ComPort/comport.fxml style type: UTILITY EXPO [INFO] Tue May 19 15:57:38 BST 2020 Open an gui EXPORT TO : log.txt
null
[INFO] Tue May 19 15:57:39 BST 2020 Load an scene ./src/main/resources/ComPort/comport.fxml style type: UTILITY EXPO [INFO] Tue May 19 15:57:39 BST 2020 Open an gui EXPORT TO : log.txt
null
[INFO] Tue May 19 16:03:47 BST 2020 Load an scene ./src/main/resources/ComPort/comport.fxml style type: UTILITY EXPO [INFO] Tue May 19 16:03:47 BST 2020 Open an gui EXPORT TO : log.txt
null
[INFO] Tue May 19 16:03:53 BST 2020 Load an scene ./src/main/resources/ComPort/comport.fxml style type: UTILITY EXPO [INFO] Tue May 19 16:03:53 BST 2020 Open an gui EXPORT TO : log.txt
null
[INFO] Tue May 19 16:03:53 BST 2020 Load an scene ./src/main/resources/ComPort/comport.fxml style type: UTILITY EXPO [INFO] Tue May 19 16:03:53 BST 2020 Open an gui EXPORT TO : log.txt
null
[INFO] Tue May 19 16:03:53 BST 2020 Load an scene ./src/main/resources/ComPort/comport.fxml style type: UTILITY EXPO [INFO] Tue May 19 16:03:53 BST 2020 Open an gui EXPORT TO : log.txt
null
[INFO] Tue May 19 16:03:53 BST 2020 Load an scene ./src/main/resources/ComPort/comport.fxml style type: UTILITY EXPO [INFO] Tue May 19 16:03:53 BST 2020 Open an gui EXPORT TO : log.txt
null
[INFO] Tue May 19 16:03:53 BST 2020 Load an scene ./src/main/resources/ComPort/comport.fxml style type: UTILITY EXPO [INFO] Tue May 19 16:03:53 BST 2020 Open an gui EXPORT TO : log.txt
null
[INFO] Tue May 19 16:03:54 BST 2020 Load an scene ./src/main/resources/ComPort/comport.fxml style type: UTILITY EXPO [INFO] Tue May 19 16:03:54 BST 2020 Open an gui EXPORT TO : log.txt
null
[INFO] Tue May 19 16:09:32 BST 2020 Load an scene ./src/main/resources/ComPort/comport.fxml style type: UTILITY EXPO [INFO] Tue May 19 16:09:32 BST 2020 Open an gui EXPORT TO : log.txt
null
[INFO] Tue May 19 16:09:33 BST 2020 Load an scene ./src/main/resources/ComPort/comport.fxml style type: UTILITY EXPO [INFO] Tue May 19 16:09:33 BST 2020 Open an gui EXPORT TO : log.txt
null
[INFO] Tue May 19 16:09:34 BST 2020 Load an scene ./src/main/resources/ComPort/comport.fxml style type: UTILITY EXPO [INFO] Tue May 19 16:09:34 BST 2020 Open an gui EXPORT TO : log.txt
null
[INFO] Tue May 19 16:09:34 BST 2020 Load an scene ./src/main/resources/ComPort/comport.fxml style type: UTILITY EXPO [INFO] Tue May 19 16:09:34 BST 2020 Open an gui EXPORT TO : log.txt
null
[INFO] Tue May 19 16:09:36 BST 2020 Load an scene ./src/main/resources/ComPort/comport.fxml style type: UTILITY EXPO [INFO] Tue May 19 16:09:36 BST 2020 Open an gui EXPORT TO : log.txt
null
[INFO] Tue May 19 16:09:36 BST 2020 Load an scene ./src/main/resources/ComPort/comport.fxml style type: UTILITY EXPO [INFO] Tue May 19 16:09:36 BST 2020 Open an gui EXPORT TO : log.txt
null
[INFO] Tue May 19 16:09:36 BST 2020 Load an scene ./src/main/resources/ComPort/comport.fxml style type: UTILITY EXPO [INFO] Tue May 19 16:09:36 BST 2020 Open an gui EXPORT TO : log.txt
null
[INFO] Tue May 19 16:09:37 BST 2020 Load an scene ./src/main/resources/ComPort/comport.fxml style type: UTILITY EXPO [INFO] Tue May 19 16:09:37 BST 2020 Open an gui EXPORT TO : log.txt
null
[INFO] Tue May 19 16:09:37 BST 2020 Load an scene ./src/main/resources/ComPort/comport.fxml style type: UTILITY EXPO [INFO] Tue May 19 16:09:37 BST 2020 Open an gui EXPORT TO : log.txt
null
[INFO] Tue May 19 16:09:37 BST 2020 Load an scene ./src/main/resources/ComPort/comport.fxml style type: UTILITY EXPO [INFO] Tue May 19 16:09:37 BST 2020 Open an gui EXPORT TO : log.txt
null
[INFO] Tue May 19 16:09:37 BST 2020 Load an scene ./src/main/resources/ComPort/comport.fxml style type: UTILITY EXPO [INFO] Tue May 19 16:09:37 BST 2020 Open an gui EXPORT TO : log.txt
null
[INFO] Tue May 19 16:09:37 BST 2020 Load an scene ./src/main/resources/ComPort/comport.fxml style type: UTILITY EXPO [INFO] Tue May 19 16:09:38 BST 2020 Open an gui EXPORT TO : log.txt
null
[INFO] Tue May 19 16:09:38 BST 2020 Load an scene ./src/main/resources/ComPort/comport.fxml style type: UTILITY EXPO [INFO] Tue May 19 16:09:38 BST 2020 Open an gui EXPORT TO : log.txt
null
[INFO] Tue May 19 16:09:38 BST 2020 Load an scene ./src/main/resources/ComPort/comport.fxml style type: UTILITY EXPO [INFO] Tue May 19 16:09:38 BST 2020 Open an gui EXPORT TO : log.txt
null

Author

## alex5250 (https://github.com/alex5250) commented on 26 May

## Fixed in #844KZDFU

Author

## alex5250 (https://github.com/alex5250) closed this on 26 May

Remember, contributions to this repository should follow our GitHub Community Guidelines. (https://docs.github.com/articles/github-community-guidelines)

## Leave a comment

Attach files by dragging & dropping, selecting or pasting them.

## Choose Files No file chosen

## Reopen issue Comment

Assignees

Labels
None yet

Projects

Milestone

Linked pull requests

You’re receiving notifications because you’re watching this repository.

Notifications | Customize

Unsubscribe

© 2020 GitHub, Inc. | Terms (https://github.com/site/terms) | Privacy (https://github.com/site/privacy) | Security (https://github.com/security) | Status (https://githubstatus.com/) | Help (https://docs.github.com/) | Contact GitHub (https://github.com/contact) | Pricing (https://github.com/pricing) | API (https://docs.github.com/) | Training (https://services.github.com/) | Blog (https://github.blog/) | About (https://github.com/about)
Write | Preview

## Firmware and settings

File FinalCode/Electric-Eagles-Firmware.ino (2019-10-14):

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
#include <Wire.h>                          //Include the Wire.h library so we can communicate with the gyro.
#include <EEPROM.h>
#include <HCSR04.h>                      //Include the EEPROM.h library so we can store information onto the EEPROM
//------------------------------SETTINGS-----------------------------
#define DEBUG 0 // Turn on debug mode
#define TEST_MODE 0 // Turn on test mode 
#define ESC_AUTOCALIBRATE 0 // Turn on ESC_AUTOCALIBRATE
#define ULTRASONIC_STBILISTATION_LINERAR 0 // Turn on ULTRASONIC_STBILISTATION_LINERAR
#define ULTRASONIC_STBILISTATION_SQERICAL 0// Turn on ULTRASONIC_STBILISTATION_SQERICAL
#define ULTRASONIC_STBILISTATION_PROCENTAL 0// Turn on ULTRASONIC_STBILISTATION_PROCENTAL
#define ULTRASONIC_STBILISTATION_DISABLED 0// Turn on ULTRASONIC_STBILISTATION_DISABLED
#define BLUETOOH 0 // Turn on BLUETOOH
#define TIMEPERIOD 0 // Sets TIMEPERIOD between x1 data and x2 data
#define ULTRASONIC_1_PIN_1 13 // Sets ultrasonics pin
#define ULTRASONIC_1_PIN_2 12 // Sets ultrasonics pin
#define MEAN_COUNT 0 //Sets mean buffer
#define MAX_VALUE 300 // MAX VALUE
int loops = 0; 
int sum=0;
//------------------------------------SETTINGS--------------------------------------
//-------------------------------------------------------SETTINGS-----------------------------------
UltraSonicDistanceSensor distanceSensor (ULTRASONIC_1_PIN_1, ULTRASONIC_1_PIN_2); // Creating a object for ULTRASONIC
//----------------------------------------------------------PID gain and limit settings---------------------------
///////////////////////////////////////////////////////////////////////////////////////////////////////////////////////////////////////
//PID gain and limit settings
///////////////////////////////////////////////////////////////////////////////////////////////////////////////////////////////////////
float pid_p_gain_roll = 1.3;               //Gain setting for the roll P-controller
float pid_i_gain_roll = 0.04;              //Gain setting for the roll I-controller
float pid_d_gain_roll = 18.0;              //Gain setting for the roll D-controller
int pid_max_roll = 400;                    //Maximum output of the PID-controller (+/-)

float pid_p_gain_pitch = pid_p_gain_roll;  //Gain setting for the pitch P-controller.
float pid_i_gain_pitch = pid_i_gain_roll;  //Gain setting for the pitch I-controller.
float pid_d_gain_pitch = pid_d_gain_roll;  //Gain setting for the pitch D-controller.
int pid_max_pitch = pid_max_roll;          //Maximum output of the PID-controller (+/-)

float pid_p_gain_yaw = 4.0;                //Gain setting for the pitch P-controller. //4.0
float pid_i_gain_yaw = 0.02;               //Gain setting for the pitch I-controller. //0.02
float pid_d_gain_yaw = 0.0;                //Gain setting for the pitch D-controller.
int pid_max_yaw = 400;                     //Maximum output of the PID-controller (+/-)

boolean auto_level = true;                 //Auto level on (true) or off (false)

///////////////////////////////////////////////////////////////////////////////////////////////////////////////////////////////////////
//Declaring global variables
///////////////////////////////////////////////////////////////////////////////////////////////////////////////////////////////////////
byte last_channel_1, last_channel_2, last_channel_3, last_channel_4;
byte eeprom_data[36];
byte highByte, lowByte;
volatile int receiver_input_channel_1, receiver_input_channel_2, receiver_input_channel_3, receiver_input_channel_4;
int counter_channel_1, counter_channel_2, counter_channel_3, counter_channel_4, loop_counter;
int esc_1, esc_2, esc_3, esc_4;
int throttle, battery_voltage;
int cal_int, start, gyro_address;
int receiver_input[5];
int temperature;
int acc_axis[4], gyro_axis[4];
float roll_level_adjust, pitch_level_adjust;

long acc_x, acc_y, acc_z, acc_total_vector;
unsigned long timer_channel_1, timer_channel_2, timer_channel_3, timer_channel_4, esc_timer, esc_loop_timer;
unsigned long timer_1, timer_2, timer_3, timer_4, current_time;
unsigned long loop_timer;
double gyro_pitch, gyro_roll, gyro_yaw;
double gyro_axis_cal[4];
float pid_error_temp;
float pid_i_mem_roll, pid_roll_setpoint, gyro_roll_input, pid_output_roll, pid_last_roll_d_error;
float pid_i_mem_pitch, pid_pitch_setpoint, gyro_pitch_input, pid_output_pitch, pid_last_pitch_d_error;
float pid_i_mem_yaw, pid_yaw_setpoint, gyro_yaw_input, pid_output_yaw, pid_last_yaw_d_error;
float angle_roll_acc, angle_pitch_acc, angle_pitch, angle_roll;
boolean gyro_angles_set;
long convert(long x, long in_min, long in_max, long out_min, long out_max) { // Math map funcion
  return (x - in_min) * (out_max - out_min) / (in_max - in_min) + out_min; // Math formula
}
unsigned long previousMillis = 0; // Set previousMillis varible = 0
boolean wait(int interval) { // Set funcion
  unsigned long currentMillis = millis(); // Set currentMillis= millis()
  if (currentMillis - previousMillis >= interval) { // Check if interval is bigger than these varibles subtraction
    previousMillis = currentMillis; // Set currentMillis= previousMillis
    return true; // return true if all okay
  }
  return false; //  else return false
}
float ultrasoincs() { // Utrasonics data mean get funicon
  if (loops > MEAN_COUNT) { // if loops ( varible) the same that MEAN_COUNT
    float nowresult = sum / loops; // Calculate a nowresult
    loops = 0; // Set loops zero
    sum = sum + distanceSensor.measureDistanceCm(); // sum a sum + distanceSensor
    return nowresult; // retun result
  }
  sum = sum + distanceSensor.measureDistanceCm(); // sum a sum + distanceSensor
  loops++; // add one for loops ! On maths lang. n+1
}
void stabilisaton_funcion_linear(int timeperiod) { // funcion
  int distaneone = (int)ultrasoincs(); // set data form prev. funcion plus conver it to int
  while (receiver_input_channel_3 < 1500 && receiver_input_channel_3 > 1600) // if receiver_input_channel_3 is a smaller than 1500 but bigget than 1600 do this code
  {
    while (wait(timeperiod)) // wait a period
    {
      int distancetwo =  (int)ultrasoincs(); // set data form prev. funcion plus conver it to int
      float trolinte = (distancetwo - distaneone) * 2000 / 300; // usnig math formula calculate it
      receiver_input_channel_3 = (int)trolinte; //set it
    }
  }
}
void stabilisaton_funcion_sqear( int timeperiod) {// funcion
  int distaneone = (int)ultrasoincs(); // set data form prev. funcion plus conver it to int
  while (receiver_input_channel_3 < 1500 && receiver_input_channel_3 > 1600) // if receiver_input_channel_3 is a smaller than 1500 but bigget than 1600 do this code
  {
    {
      while (wait(timeperiod)) // wait a period
      {
        int distancetwo =  (int)ultrasoincs();// set data form prev. funcion plus conver it to int
        float add_error = (distancetwo - distaneone) * (distancetwo - distaneone); // usnig math formula calculate it
        receiver_input_channel_3 = receiver_input_channel_3 + add_error; //set it
      }
    }
  }
}

void stabilisaton_funcion_perentage(int timeperiod) { // funcion
  int distaneone =  (int)ultrasoincs(); // set data form prev. funcion plus conver it to int
  while (receiver_input_channel_3 < 1500 && receiver_input_channel_3 > 1600) // if receiver_input_channel_3 is a smaller than 1500 but bigget than 1600 do this code
  {
    while (wait(timeperiod))  // wait a period
    {
      int distancetwo =  (int)ultrasoincs();  // set data form prev. funcion plus conver it to int
      float add_error = convert((distancetwo - distaneone) / MAX_VALUE * 100, 0, 100, 1000, 2000); //mathformula
      receiver_input_channel_3 = add_error; //set it
    }
  }
}

void gyroprint() { // Print gyro data
  if (DEBUG == 1) // Check if gyro ==1
  {
    Serial.print(acc_x); // Print
    Serial.print(", ");// Print demiter
    Serial.print(acc_y);// Print
    Serial.print(", ");// Print demiter
    Serial.print(acc_z);// Print
  }
}
void check_ultrasonics() { // Check check_ultrasonics settings
  if (ULTRASONIC_STBILISTATION_LINERAR == 1) { //Check check_ultrasonics settings
    stabilisaton_funcion_linear(TIMEPERIOD); //call funcions
  }
  if (ULTRASONIC_STBILISTATION_SQERICAL == 1) {//Check check_ultrasonics settings
    stabilisaton_funcion_sqear(TIMEPERIOD); //call funcions
  }
  if (ULTRASONIC_STBILISTATION_PROCENTAL == 1) {//Check check_ultrasonics settings
    stabilisaton_funcion_perentage(TIMEPERIOD); //call funcions
  }
  if (ULTRASONIC_STBILISTATION_DISABLED == 1) {//Check check_ultrasonics settings
  }
}

///////////////////////////////////////////////////////////////////////////////////////////////////////////////////////////////////////
//Setup routine
///////////////////////////////////////////////////////////////////////////////////////////////////////////////////////////////////////
void setup() {
  Serial.begin(57600);
  Serial.println(" █▀▀ █░░ █▀▀ █▀▀ ▀▀█▀▀ █▀▀█ ░▀░ █▀▀   █▀▀ █▀▀█ █▀▀▀ █░░ █▀▀ █▀▀");
  Serial.println(" █▀▀ █░░ █▀▀ █▀▀ ▀▀█▀▀ █▀▀█ ░▀░ █▀▀   █▀▀ █▀▀█ █▀▀▀ █░░ █▀▀ █▀▀");
  Serial.println(" █▀▀ █░░ █▀▀ █░░ ░░█░░ █▄▄▀ ▀█▀ █░░   █▀▀ █▄▄█ █░▀█ █░░ █▀▀ ▀▀█");
  Serial.println(" ▀▀▀ ▀▀▀ ▀▀▀ ▀▀▀ ░░▀░░ ▀░▀▀ ▀▀▀ ▀▀▀   ▀▀▀ ▀░░▀ ▀▀▀▀ ▀▀▀ ▀▀▀ ▀▀▀");
  //Copy the EEPROM data for fast access data.
  for (start = 0; start <= 35; start++)eeprom_data[start] = EEPROM.read(start);
  start = 0;                                                                //Set start back to zero.
  gyro_address = eeprom_data[32];                                           //Store the gyro address in the variable.

  Wire.begin();                                                             //Start the I2C as master.

  TWBR = 12;                                                                //Set the I2C clock speed to 400kHz.

  //Arduino (Atmega) pins default to inputs, so they don't need to be explicitly declared as inputs.
  DDRD |= B11110000;                                                        //Configure digital poort 4, 5, 6 and 7 as output.
  DDRB |= B00110000;                                                        //Configure digital poort 12 and 13 as output.

  //Use the led on the Arduino for startup indication.
  digitalWrite(13, HIGH);                                                   //Turn on the warning led.

  //Check the EEPROM signature to make sure that the setup program is executed.
  while (eeprom_data[33] != 'J' || eeprom_data[34] != 'M' || eeprom_data[35] != 'B')delay(10);

  //The flight controller needs the MPU-6050 with gyro and accelerometer
  //If setup is completed without MPU-6050 stop the flight controller program
  if (eeprom_data[31] == 2 || eeprom_data[31] == 3)delay(10);

  set_gyro_registers();                                                     //Set the specific gyro registers.

  for (cal_int = 0; cal_int < 1250 ; cal_int ++) {                          //Wait 5 seconds before continuing.
    PORTD |= B11110000;                                                     //Set digital poort 4, 5, 6 and 7 high.
    delayMicroseconds(1000);                                                //Wait 1000us.
    PORTD &= B00001111;                                                     //Set digital poort 4, 5, 6 and 7 low.
    delayMicroseconds(3000);                                                //Wait 3000us.
  }

  //Let's take multiple gyro data samples so we can determine the average gyro offset (calibration).
  for (cal_int = 0; cal_int < 2000 ; cal_int ++) {                          //Take 2000 readings for calibration.
    if (cal_int % 15 == 0)digitalWrite(12, !digitalRead(12));               //Change the led status to indicate calibration.
    gyro_signalen();                                                        //Read the gyro output.
    gyro_axis_cal[1] += gyro_axis[1];                                       //Ad roll value to gyro_roll_cal.
    gyro_axis_cal[2] += gyro_axis[2];                                       //Ad pitch value to gyro_pitch_cal.
    gyro_axis_cal[3] += gyro_axis[3];                                       //Ad yaw value to gyro_yaw_cal.
    //We don't want the esc's to be beeping annoyingly. So let's give them a 1000us puls while calibrating the gyro.
    PORTD |= B11110000;                                                     //Set digital poort 4, 5, 6 and 7 high.
    delayMicroseconds(1000);                                                //Wait 1000us.
    PORTD &= B00001111;                                                     //Set digital poort 4, 5, 6 and 7 low.
    delay(3);                                                               //Wait 3 milliseconds before the next loop.
  }
  //Now that we have 2000 measures, we need to devide by 2000 to get the average gyro offset.
  gyro_axis_cal[1] /= 2000;                                                 //Divide the roll total by 2000.
  gyro_axis_cal[2] /= 2000;                                                 //Divide the pitch total by 2000.
  gyro_axis_cal[3] /= 2000;                                                 //Divide the yaw total by 2000.

  PCICR |= (1 << PCIE0);                                                    //Set PCIE0 to enable PCMSK0 scan.
  PCMSK0 |= (1 << PCINT0);                                                  //Set PCINT0 (digital input 8) to trigger an interrupt on state change.
  PCMSK0 |= (1 << PCINT1);                                                  //Set PCINT1 (digital input 9)to trigger an interrupt on state change.
  PCMSK0 |= (1 << PCINT2);                                                  //Set PCINT2 (digital input 10)to trigger an interrupt on state change.
  PCMSK0 |= (1 << PCINT3);                                                  //Set PCINT3 (digital input 11)to trigger an interrupt on state change.

  //Wait until the receiver is active and the throtle is set to the lower position.
  while (receiver_input_channel_3 < 990 || receiver_input_channel_3 > 1020 || receiver_input_channel_4 < 1400) {
    receiver_input_channel_3 = convert_receiver_channel(3);                 //Convert the actual receiver signals for throttle to the standard 1000 - 2000us
    receiver_input_channel_4 = convert_receiver_channel(4);                 //Convert the actual receiver signals for yaw to the standard 1000 - 2000us
    start ++;                                                               //While waiting increment start whith every loop.
    //We don't want the esc's to be beeping annoyingly. So let's give them a 1000us puls while waiting for the receiver inputs.
    PORTD |= B11110000;                                                     //Set digital poort 4, 5, 6 and 7 high.
    delayMicroseconds(1000);                                                //Wait 1000us.
    PORTD &= B00001111;                                                     //Set digital poort 4, 5, 6 and 7 low.
    delay(3);                                                               //Wait 3 milliseconds before the next loop.
    if (start == 125) {                                                     //Every 125 loops (500ms).
      digitalWrite(13, !digitalRead(13));                                   //Change the led status.
      start = 0;                                                            //Start again at 0.
    }
  }
  start = 0;                                                                //Set start back to 0.

  //Load the battery voltage to the battery_voltage variable.
  //65 is the voltage compensation for the diode.
  //12.6V equals ~5V @ Analog 0.
  //12.6V equals 1023 analogRead(0).
  //1260 / 1023 = 1.2317.
  //The variable battery_voltage holds 1050 if the battery voltage is 10.5V.
  battery_voltage = (analogRead(0) + 65) * 1.2317;

  loop_timer = micros();                                                    //Set the timer for the next loop.

  //When everything is done, turn off the led.
  digitalWrite(13, LOW);
  tone(4, 294);
  tone(5, 294);
  tone(6, 294);
  tone(7, 294);
  delay(1000);
  noTone(4);
  noTone(5);
  noTone(6);
  noTone(7);                           //Turn off the warning led.
}
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

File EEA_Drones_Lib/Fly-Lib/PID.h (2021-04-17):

// Electris Eagles P-I-D Settings. Config Generated at : Sat Feb 29 23:00:02 EET 2020
#define p_gain_roll 4.0
#define i_gain_roll 0.04
#define d_gain_roll 13.9
#define p_gain_yaw 5.0
#define i_gain_yaw 2.0
#define d_gain_yaw 1.0

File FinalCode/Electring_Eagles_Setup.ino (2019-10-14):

///////////////////////////////////////////////////////////////////////////////////////
//Terms of use
///////////////////////////////////////////////////////////////////////////////////////
//THE SOFTWARE IS PROVIDED "AS IS", WITHOUT WARRANTY OF ANY KIND, EXPRESS OR
//IMPLIED, INCLUDING BUT NOT LIMITED TO THE WARRANTIES OF MERCHANTABILITY,
//FITNESS FOR A PARTICULAR PURPOSE AND NONINFRINGEMENT. IN NO EVENT SHALL THE
//AUTHORS OR COPYRIGHT HOLDERS BE LIABLE FOR ANY CLAIM, DAMAGES OR OTHER
//LIABILITY, WHETHER IN AN ACTION OF CONTRACT, TORT OR OTHERWISE, ARISING FROM,
//OUT OF OR IN CONNECTION WITH THE SOFTWARE OR THE USE OR OTHER DEALINGS IN
//THE SOFTWARE.
///////////////////////////////////////////////////////////////////////////////////////
//Safety note
///////////////////////////////////////////////////////////////////////////////////////
//Always remove the propellers and stay away from the motors unless you
//are 100% certain of what you are doing.
///////////////////////////////////////////////////////////////////////////////////////
//Edited by Electrics Eagles
/*
   █▀▀ █░░ █▀▀ █▀▀ ▀▀█▀▀ █▀▀█ ░▀░ █▀▀   █▀▀ █▀▀█ █▀▀▀ █░░ █▀▀ █▀▀
   █▀▀ █░░ █▀▀ █▀▀ ▀▀█▀▀ █▀▀█ ░▀░ █▀▀   █▀▀ █▀▀█ █▀▀▀ █░░ █▀▀ █▀▀
   █▀▀ █░░ █▀▀ █░░ ░░█░░ █▄▄▀ ▀█▀ █░░   █▀▀ █▄▄█ █░▀█ █░░ █▀▀ ▀▀█
   ▀▀▀ ▀▀▀ ▀▀▀ ▀▀▀ ░░▀░░ ▀░▀▀ ▀▀▀ ▀▀▀   ▀▀▀ ▀░░▀ ▀▀▀▀ ▀▀▀ ▀▀▀ ▀▀▀
*/

#include <Wire.h>               //Include the Wire.h library so we can communicate with the gyro
#include <EEPROM.h>             //Include the EEPROM.h library so we can store information onto the EEPROM
#include <HCSR04.h>
#define U1 12
#define U2 12
UltraSonicDistanceSensor distanceSensor(U1, U2);  // Initialize sensor that uses digital pins 13 and 12.
//Declaring Global Variables
byte last_channel_1, last_channel_2, last_channel_3, last_channel_4;
byte lowByte, highByte, type, gyro_address, error, clockspeed_ok;
byte channel_1_assign, channel_2_assign, channel_3_assign, channel_4_assign;
byte roll_axis, pitch_axis, yaw_axis;
byte receiver_check_byte, gyro_check_byte;
volatile int receiver_input_channel_1, receiver_input_channel_2, receiver_input_channel_3, receiver_input_channel_4;
int center_channel_1, center_channel_2, center_channel_3, center_channel_4;
int high_channel_1, high_channel_2, high_channel_3, high_channel_4;
int low_channel_1, low_channel_2, low_channel_3, low_channel_4;
int address, cal_int;
unsigned long timer, timer_1, timer_2, timer_3, timer_4, current_time;
float gyro_pitch, gyro_roll, gyro_yaw;
float gyro_roll_cal, gyro_pitch_cal, gyro_yaw_cal;
void ultrasonic_check()
{
  Serial.println(F("==================================================="));
  Serial.println(F("Ultrasonics setup"));
  Serial.println(F("==================================================="));
  Serial.println(F("Checking ultrasonic now...................."));
  if (distanceSensor.measureDistanceCm() > 1 &&  distanceSensor.measureDistanceCm()  < 300)
  {
    error = 0;
    Serial.println(F("Sucessful checked utrasonic sensor"));
    Serial.println(F("==================================================="));
    Serial.println(F("Ultrasonics setup .... OK"));
    Serial.println(F("==================================================="));
    Serial.println(F("Checking ultrasonic now....................OK"));
  }
  else {
    error = 1;
    Serial.println(F("[ERROR 9 ] Check Utrasonic sensor"));
  }

}

//Setup routine
void setup() {
  pinMode(12, OUTPUT);
  //Arduino (Atmega) pins default to inputs, so they don't need to be explicitly declared as inputs
  PCICR |= (1 << PCIE0);    // set PCIE0 to enable PCMSK0 scan
  PCMSK0 |= (1 << PCINT0);  // set PCINT0 (digital input 8) to trigger an interrupt on state change
  PCMSK0 |= (1 << PCINT1);  // set PCINT1 (digital input 9)to trigger an interrupt on state change
  PCMSK0 |= (1 << PCINT2);  // set PCINT2 (digital input 10)to trigger an interrupt on state change
  PCMSK0 |= (1 << PCINT3);  // set PCINT3 (digital input 11)to trigger an interrupt on state change
  Wire.begin();             //Start the I2C as master
  Serial.begin(57600);      //Start the serial connetion @ 57600bps
  delay(250);               //Give the gyro time to start
}
//Main program
void loop() {
  //Show the YMFC-3D V2 intro
  intro();

  Serial.println(F(""));
  Serial.println(F("==================================================="));
  Serial.println(F("System check"));
  Serial.println(F("==================================================="));
  delay(1000);
  Serial.println(F("Checking I2C clock speed."));
  delay(1000);

  TWBR = 12;                      //Set the I2C clock speed to 400kHz.

#if F_CPU == 16000000L          //If the clock speed is 16MHz include the next code line when compiling
  clockspeed_ok = 1;            //Set clockspeed_ok to 1
#endif                          //End of if statement

  if (TWBR == 12 && clockspeed_ok) {
    Serial.println(F("I2C clock speed is correctly set to 400kHz."));
  }
  else {
    Serial.println(F("I2C clock speed is not set to 400kHz. (ERROR 8)"));
    error = 1;
  }

  if (error == 0) {
    Serial.println(F(""));
    Serial.println(F("==================================================="));
    Serial.println(F("Transmitter setup"));
    Serial.println(F("==================================================="));
    delay(1000);
    Serial.print(F("Checking for valid receiver signals."));
    //Wait 10 seconds until all receiver inputs are valid
    wait_for_receiver();
    Serial.println(F(""));
  }
  //Quit the program in case of an error
  if (error == 0) {
    delay(2000);
    Serial.println(F("Place all sticks and subtrims in the center position within 10 seconds."));
    for (int i = 9; i > 0; i--) {
      delay(1000);
      Serial.print(i);
      Serial.print(" ");
    }
    Serial.println(" ");
    //Store the central stick positions
    center_channel_1 = receiver_input_channel_1;
    center_channel_2 = receiver_input_channel_2;
    center_channel_3 = receiver_input_channel_3;
    center_channel_4 = receiver_input_channel_4;
    Serial.println(F(""));
    Serial.println(F("Center positions stored."));
    Serial.print(F("Digital input 08 = "));
    Serial.println(receiver_input_channel_1);
    Serial.print(F("Digital input 09 = "));
    Serial.println(receiver_input_channel_2);
    Serial.print(F("Digital input 10 = "));
    Serial.println(receiver_input_channel_3);
    Serial.print(F("Digital input 11 = "));
    Serial.println(receiver_input_channel_4);
    Serial.println(F(""));
    Serial.println(F(""));
  }
  if (error == 0) {
    Serial.println(F("Move the throttle stick to full throttle and back to center"));
    //Check for throttle movement
    check_receiver_inputs(1);
    Serial.print(F("Throttle is connected to digital input "));
    Serial.println((channel_3_assign & 0b00000111) + 7);
    if (channel_3_assign & 0b10000000)Serial.println(F("Channel inverted = yes"));
    else Serial.println(F("Channel inverted = no"));
    wait_sticks_zero();
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

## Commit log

2019-10-02 Create PowerPoint
2020-01-08 Small Repo Fix #1
    Added a our ariceture for github in a logo`s folder. Also I add a text logo ( in logo folder offc ourse) Also I added a PowerPoint Presentation called "Found Working vector for 2020 Year with a drones"
2020-01-29 Added a PCB and PID Data
    Added:
    *PCB
    * PID Data
    *Removed LogParseTool for used tools
    *Added a tool for build PID graphs.
2020-01-29 Add Big Data Graph Tool
    [DataFromTestCopterGyro.csv]
2020-02-09 Added a modificaded code.
    Added Kalman.
    [DataFromTestCopterGyro.csv]
2020-02-11 Removed Rubbish
    [DataFromTestCopterGyro.csv]
2020-02-23 Added an new PCB
    [BoardOutline.gbr, Bottom.gbr, BottomAssy.gbr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]
2020-06-10 Add files via upload
    These files is newer version PCB and circuit. Additionally, we added GPS module. This newer module signaled from transmit via PPM signal.
    Changing type of module for gyroscope. This board will use GY-68 gyroscope.
2020-06-10 Create PCBV3
2020-08-24 Modules /Studio
    [config.txt]
2020-10-01 Fixed error in PCB
    Removed voltage regurator 3.3V in sechmatic.
    Removed additing pin in PCB (like printed board with prototype)
2023-09-15 Update Readme.md
    Георий Вильевич => George Dalidovich
